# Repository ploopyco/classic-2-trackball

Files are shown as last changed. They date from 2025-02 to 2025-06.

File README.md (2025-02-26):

# The Ploopy Classic 2 Trackball

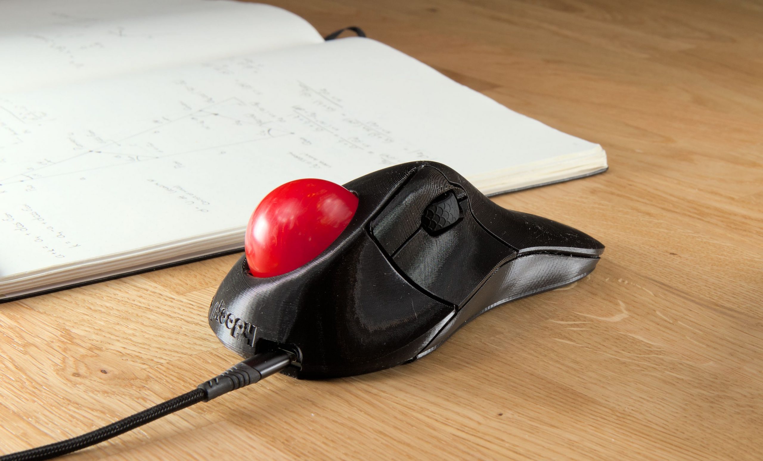
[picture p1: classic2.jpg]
The Ploopy Classic 2


By some stroke of luck, you've made your way here. The Ploopy Classic 2 Trackball. Your life will never be the same.

This repository contains all of the design and production files necessary to make a Ploopy Classic 2 Trackball. We've also included some kick-ass documentation on how to get it made, assemble it, and program it [which you can find here](https://ploopyco.github.io/classic-2-trackball/).

What are you waiting for? Your new life awaits.

## QMK?!

Kits bought from the [Ploopy store](https://ploopy.co/product-category/classic-2) come with QMK and VIA preloaded. [Check out the documentation](https://ploopyco.github.io/classic-2-trackball/) for instructions on how to load new firmware onto your device. (It's super easy!)

The firmware hex file that ships with all Classic 2 Trackballs is included in this repository as well, as `ploopyco_trackball_rev1_007_via.uf2`.

## Under what license is this released?

As per QMK's licensing requirements, the firmware for the Ploopy Classic 2 Trackball is released under GPLv3. Hardware design files, including electronics and mechanical files, are released under OHL CERN v2-S. Check the respective directories for full license text.

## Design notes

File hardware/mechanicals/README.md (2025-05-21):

## Revision J or K?

The *current* revision of the parts is Revision K. Revision J was shipped on Classic 2s prior to May of 2025.

If you're replacing parts from your current Classic 2, open it and check the Base. It should have a very prominent J or K written on it.

## Only one file? Where are the parts?

The STEP/STL files contain all of the plastic parts in one file. Doing it this way preserves the assembly information, showing how the parts are supposed to fit together, as well as the expected clearances between parts. It also bundles all of the parts for a given revision together, so there's no accidental mixing of parts from different revisions.

## How do I print this?

You'll need to split the parts in the file up before you can print them. Most slicers can do this; if you have a compatible printer we recommend PrusaSlic3r, since that's the one we use in-house and have checked.

Note that submitting this file to some 3rd party print services will cause confusion, as they are expecting one body instead of many. To do this, you can use PrusaSlic3r to split the parts and then export each separately as an STL.

## How can I use the included .3mf file?

The .3mf file was generated using PrusaSlicer v2.9. The job was generated for Prusa i3 MK2S/MK3S/MK3S+ printers. It assumes the use of PLA that is printable at 200-230C. If you have that PrusaSlicer version, such a printer, and such filament, then you're in a lot of luck! We use a .3mf job that is very similar to this one to print these parts on our printing farm.

If you do not, then using the included .3mf file is likely going to cause you a lot of headaches. If this is the case, the included .3mf file should be considered **as a reference only**. If you use it at all, it is recommended that you look at it to see what kinds of print settings we use (gyroid infill, 0.3mm layer height, part orientation, etc.). However, you should use your own slicing software to generate the .gcode files for your printer.

## Why don't you include a .gcode file?

For your safety. Uploading a .gcode file onto a printer can be extremely hazardous if that .gcode file wasn't specifically generated for that printer. We don't want to come anywhere near that sort of scenario, so we are not going to upload a .gcode file.

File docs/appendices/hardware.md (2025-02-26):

# Appendix C: Hardware

# Buying hardware from us

Getting all of the hardware on your own can be tricky because the parts you select may not fit perfectly. [That's why we sell kits with everything you need to build a Ploopy Classic 2 Trackball](https://ploopy.co/product-category/classic-2/). Here's why that's great for you:

- Everything is guaranteed to fit together perfectly
- Everything is guaranteed to work as intended
- You'll end up saving money - probably quite a bit of money - by not spending on extra parts

Your call. You'll sort it out.

# Getting your own hardware

This guide was a bit light on detail in the other sections, and that's because the hardware has to conform to many specifications. They'll all be listed here.

First, a complete list of all the hardware you'll need:

- 6x screws
- 3x MR63ZZ roller bearings
- 2x 3mm x 18mm metal dowels
- 1x silicone ring
- 4x friction pads
- 1x snooker ball

We'll be going over all of them in detail. There will be mentions of *critical specifications*; if you're going to be sourcing your own parts, **you must get parts that conform to the critical specifications**. If you go off-menu, the parts will not fit the way that we intended when we designed the Classic 2. That might mean that your Classic 2 **doesn't work**.

Let's get cracking.

## Screws

Here are the critical specifications:

- \#2
- 3/8" length

## MR63ZZ Roller Bearings

Here are the critical specifications:

- MR63ZZ bearing
- 3mm inner diameter
- 6mm outer diameter
- 2.5mm thickness

## 3mm x 18mm metal dowels

Here are the critical specifications:

- 3mm diameter
- 18mm length

## Silicone ring

We use decorative rings for this. Here are the critical specifications:

- Size 10 (19.8mm diameter)
- Width between 8.0mm and 8.7mm

## Friction pads

Here are the critical specifications:

- Circular shape
- Up to 3/4" diameter
- Up to 1/8" thickness
- Non-slip

## Snooker ball

We use 1.75-inch diameter (44.45mm) miniature snooker balls. Any ball between 44.5mm and 45.5mm should work.

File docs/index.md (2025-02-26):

# Home

So, you want to build a Ploopy Classic 2 Trackball, eh? Or, maybe you want to replace some broken parts. Maybe you want to reprogram it. Or maybe you just want to know how it all works. No matter the motivation, this is the place to learn.

**Bought a kit and itching to get it built?** --> Get started by going to the [assembly instructions](assembly-instructions.md).

**Looking to purchase a kit with everything you need to build your own Ploopy Classic 2 Trackball?** --> [Check out the Ploopy store](https://ploopy.co/product-category/classic-2).

**Building a Ploopy Classic 2 Trackball from scratch?** --> Get started by going to [Appendix A: Printed circuit boards](appendices/pcbs.md).

---

*Copyright (C) 2025 Ploopy Corporation. Permission is granted to copy, distribute and/or modify this document under the terms of the GNU Free Documentation License, Version 1.3 or any later version published by the Free Software Foundation; with no Invariant Sections, no Front-Cover Texts, and no Back-Cover Texts. A copy of the license is included in the section entitled "GNU Free Documentation License".*

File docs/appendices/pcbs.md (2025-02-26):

# Appendix A: Printed circuit boards

## Buying boards from us
Getting the Ploopy boards made can be complex, and expensive, especially if you only need one set. [That's why we sell kits with everything you need to build a Ploopy Classic 2 Trackball](https://ploopy.co/product-category/classic-2/). Here's why that's great for you:

- You get a PCB with all components soldered
- The firmware is already programmed on the microcontroller, so you won't have to program it
- It'll cost a hell of a lot less than if you do a production run of PCBs just for yourself
- You won't have to order components and wait while they come in
- We guarantee that it works

Just something to consider. You're smart. You'll figure it out.

## Making your own boards

Want to make your own Ploopy Classic 2 boards? Great! Less work for us. Seriously, though, only choose this option if you know what you're doing. You don't want to embarrass yourself, do you?

### Step 1: Order the PCBs from a PCB production company

Here are the most important configurations you'll need to communicate to the company:

- 4 layers
- FR-4, TG 150-160 (basically, whatever the cheapest option is)
- 1.6mm thickness
- 6/6mil track/spacing distance
- 0.3mm minimum hole size
- ENIG surface finish, but you can go with HASL if you don't care about lead poisoning
- 1oz copper thickness for both outer and inner layers
- Choose whatever colours you want for solder mask and silkscreen; we like white solder mask and black silkscreen

If something is missing from here, it's not really important.

At some point, you'll have to upload design files to the production company. Use the [electronics source files](https://github.com/ploopyco/classic-2-trackball/tree/master/hardware/electronics) to generate manufacturing files (you'll have to convert them from their native Altium format if you're using some other platform). That should contain everything you need to get the boards made. If the production company rejects this package, however, you'll need to address the issue yourself.

### Step 2: Order the electronics components

All of the components are described in the schematics of the PCBs. Ordering the components is left as an exercise for the reader.

A complete list of all of the components can be found in the electrical design files.

### Step 3: Get the necessary tools

- PCB
- All of the electronics components
- A hot air rework tool
- Solder paste
- A printout of the schematics

### Step 4: Solder the components to the boards

Once you've got the PCBs and all of the components, print out the schematics. Use the schematics to match the reference designators on the PCBs to the reference designators on the schematics, and then get to soldering.

If you've never soldered surface mount components before, or want a refresher on how to solder, we recommend [this video on using an iron to solder surface mount components](https://www.youtube.com/watch?v=3NN7UGWYmBY), and [this video on using a hot-air soldering station](https://www.youtube.com/watch?v=c_Qt5CtUlqY).

### Step 5: All done!

Congrats, you finished assembling the electronics! Pat yourself on the back.

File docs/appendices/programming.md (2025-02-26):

# Appendix D: QMK Firmware Programming

## Working with QMK

Ploopy devices are fairly easy to program and reprogram, thanks to the excellent work by all of the developers and maintainers of the [QMK firmware suite](https://github.com/qmk/qmk_firmware).

## Before you begin

If you have never used QMK before, go through [all of the steps in the QMK guide to set up your environment](https://docs.qmk.fm/#/newbs_getting_started).

QMK was built for keyboards, so you'll see lots of references to code that looks like the following:

`-kb <keyboard>`

Whenever you see that, use the following syntax:

`-kb ploopyco/trackball`

and you'll be fine.

## Building the Ploopy device firmware

Using QMK MSYS or your compilation toolchain of choice, compile the firmware with the following command:

`qmk compile -kb ploopyco/trackball/rev1_007 -km default`

Note: in the QMK namespace, the Classic (both the original and the Classic 2) is simply called "trackball". `rev1_007` is the firmware that ships on the Classic 2.

For more details on building QMK firmware in general, see the [QMK firmware guide](https://docs.qmk.fm/#/newbs_building_firmware).

## Putting the Ploopy device into bootloader mode

Putting the Ploopy device into bootloader mode is very simple and straightforward.

1. Unplug the device from your computer.
2. Hold the "back" button. This is the button just to the right of the ball; it normally sits under your ring (fourth) finger.
6. While holding the button, plug the Ploopy device into your computer..
7. The computer should recognise that a mass storage device was just plugged in. Once this is done, you should be able to drag and drop files onto the Ploopy device, as if the board was a USB drive. Feel free to remove the tweezers or paperclip at this point.

And that's it. While plugged in this way, the Ploopy device will accept new firmware.

If you want to upload a new firmware file (a ".uf2" file, like "ploopy_classic_2_v42069" or something), just drag it into the folder, and it'll automatically install on the Ploopy device and restart itself.

Whenever you want to put new firmware onto the Ploopy device, go through these steps again.

**TIP**: If your firmware is in some kind of strange state and uploading new firmware isn't fixing it, try uploading [a flash nuke](https://learn.adafruit.com/getting-started-with-raspberry-pi-pico-circuitpython/circuitpython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) to the Classic 2 before flashing the new firmware. It wipes the memory of the Trackpad completely clean, which can help clear a few types of errors.

## Putting the Ploopy device into bootloader mode if it's bricked

Putting the Ploopy device into bootloader mode if it's bricked is a bit more involved, but still doable.

1. Unplug it from your computer.
2. Open it by removing the screws in the Base and removing the Top.
3. Look for a pair of vias (gold-plated holes) on the board, with the text `BOOT LOADER` close by.
4. Get a paper clip (non-insulated, i.e. no plastic shit covering it) or a pair of tweezers, or some wire. Whatever you've got on hand that's metal.
5. Stick the paper clip or tweezers into the holes. You're trying to form an electrical connection between the two holes.
6. While you've got the two vias connected with your metal bridge, plug the Ploopy device into your computer.
7. The computer should recognise that a mass storage device was just plugged in. Once this is done, you should be able to drag and drop files onto the Ploopy device, as if the board was a USB drive. Feel free to remove the tweezers or paperclip at this point.

And that's it. While plugged in this way, the Ploopy device will accept new firmware.

## And that's it!

Happy customizing!

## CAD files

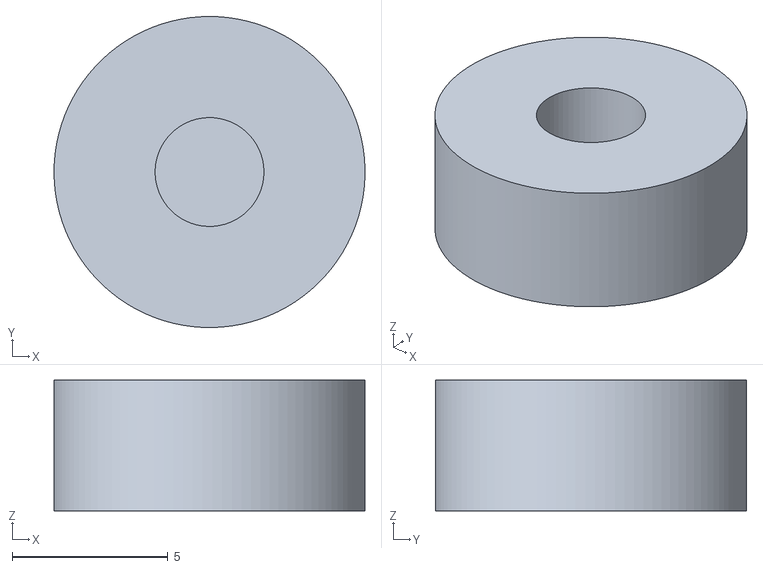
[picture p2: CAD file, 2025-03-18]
hardware/mechanicals/Bearing Press Jig Bottom.stl
10.00 x 10.00 x 4.20

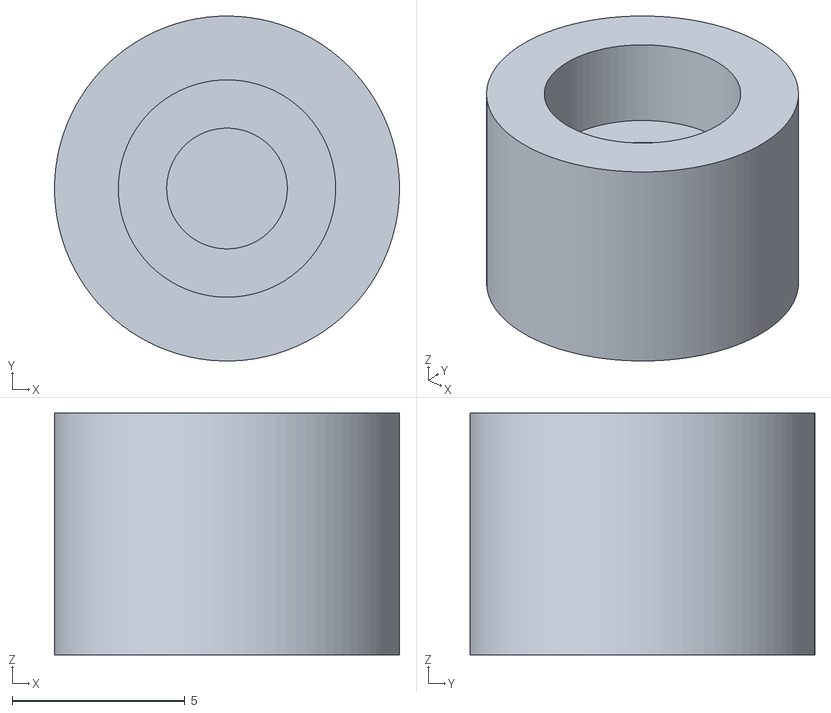
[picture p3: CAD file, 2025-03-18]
hardware/mechanicals/Bearing Press Jig Top.stl
10.00 x 10.00 x 7.00

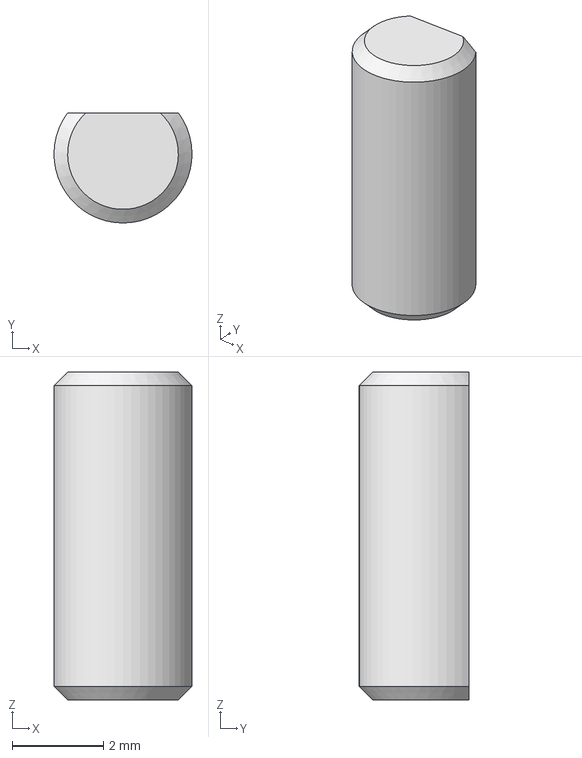
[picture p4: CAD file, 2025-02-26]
hardware/mechanicals/RollerBearingDowel.stp
3.03 x 2.42 x 7.20 mm

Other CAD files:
hardware/mechanicals/RollerBearingDowel.stl

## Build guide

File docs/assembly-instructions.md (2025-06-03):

# Ploopy Kit Assembly Instructions

## BEFORE YOU DO ANYTHING, READ THIS FIRST.

**Do not flash new firmware until you've verified that the electronics are all working.**

That means, finish building the Classic 2, plug it in, use the stock firmware for about five minutes. Verify that the cursor is moving, and all the buttons are working.

Once you've verified that it all works, you're good to go flashing new firmware.

## Do I have the right version of the Classic Trackball?

This guide is for building the Classic 2 Trackball. If your Classic kit has a large, bulky USB-B port on it, [you're looking for the original Classic assembly instructions, here](https://github.com/ploopyco/classic-trackball).

If your Classic has a **USB-C** connector on it, read onwards!

## Main Instructions


In this section, you'll go over how to build a Classic 2 from the official Ploopy Classic 2 kit.

Here's how these instructions are structured*:

- 💡 Comments with a lightbulb are good information to know.
- ➡️ Comments with an arrow are commands. Execute them when you encounter them.
- ✅ Comments with a checkmark are verification steps. Check what they tell you to check, and if it's all good, move on.
- 📷 Comments with a camera are references to photos. Check the corresponding image for guidance.

Most steps have photos, so if you need some additional visual help, consult the images.

Note that some of these pictures were taken at different times, so they may show a bit of inconsistency in between steps.

*\* Thanks to [schneems](https://github.com/schneems) for his [great suggestions on how to write documentation](https://github.com/ploopyco/headphones/issues/37).*

### Step 1

- ➡️ Get a soldering iron and solder.
- ➡️ Get a #1 Phillips head screwdriver (or similar; you're looking for a small-ish screwdriver here).
- 💡 A pair of needle-nose pliers and a pair of tweezers are optional, but they'll make future steps easier.

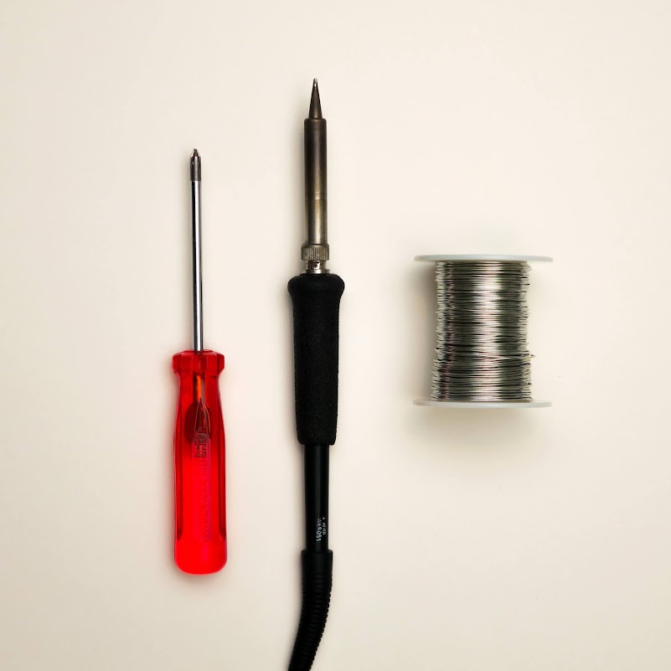
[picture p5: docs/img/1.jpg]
|  |
|:--:|
| *Figure 1: Necessary tools* |

### Step 2

- 💡 In the photo, a "tab" is being pulled by a pair of pliers.
- 💡 There may be up to two small tabs on the outside of the PCB.
- 💡 A pair of pliers will help to gently break the tabs off.
- ➡️ Break any leftover tabs off the PCB.

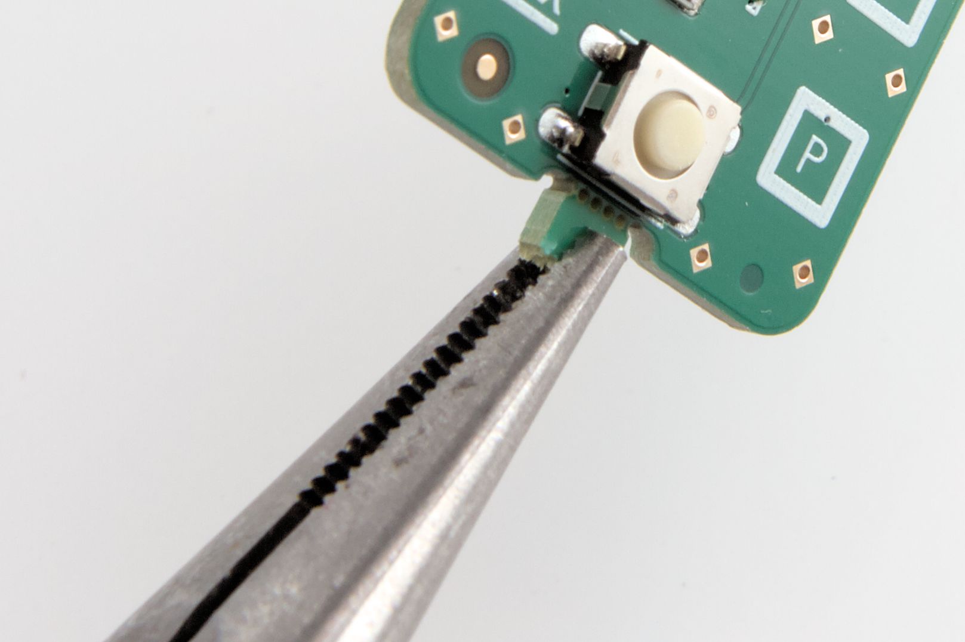
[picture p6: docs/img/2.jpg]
|  |
|:--:|
| *Figure 2: Breaking off tabs* |

### Step 3

- ➡️ Get the Base PCB and the PMW-3360.
- 💡 The PMW-3360 comes on a pink foam. This is a special anti-static foam that protects the PMW-3360 when it's being transported.
- ➡️ Remove the PMW-3360 from its foam.
- 💡 It is very, very easy to solder the PMW-3360 incorrectly. This mistake is almost impossible to fix and will permanently ruin the Classic 2. Follow the next steps very carefully.
- ✅ Make sure that you see the "Pin 1" dot on the PMW-3360. It's a small, white dot on the back of the chip. 📷 *See Figure 3.1 for details.*
- ✅ Make sure that you see the "1" designator on the Base PCB. 📷 *See Figure 3.2 for details.*
- 💡 The "Pin 1" dot on the PMW-3360 must be lined up correctly with the "1" designator on the Base PCB. 📷 *See Figure 3.3 for a photo showing the correct orientation of the sensor.*
- ➡️ Insert, but **do not solder**, the PMW-3360 into the Base PCB.

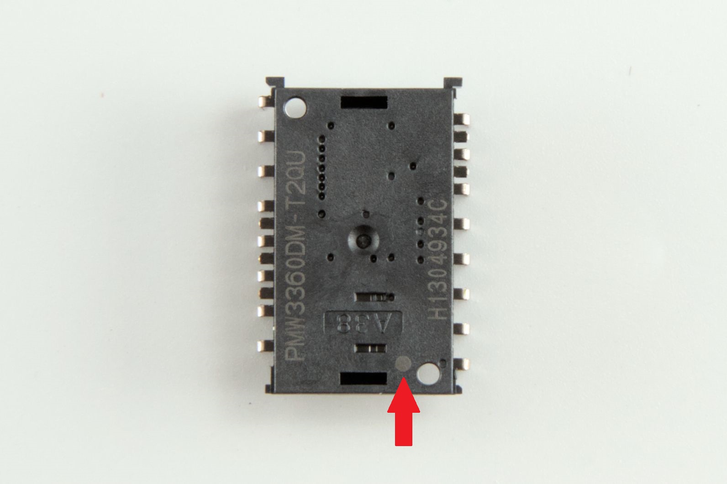
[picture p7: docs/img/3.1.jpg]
|  |
|:--:|
| *Figure 3.1: Pin 1 dot on the PMW-3360* |

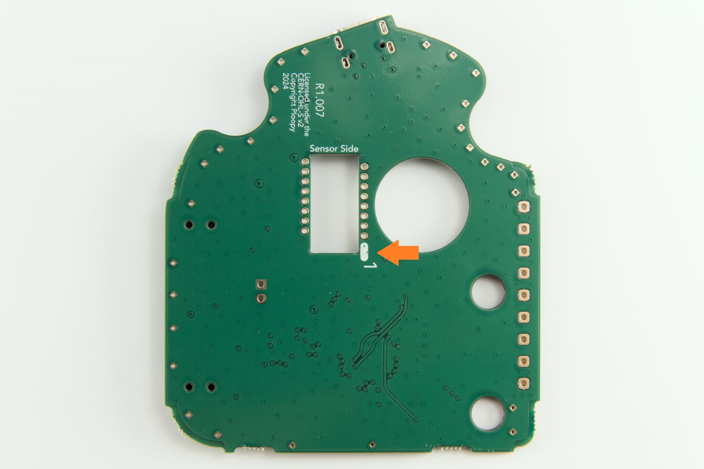
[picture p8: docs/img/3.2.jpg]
|  |
|:--:|
| *Figure 3.2: Pin 1 dot on the Base PCB* |

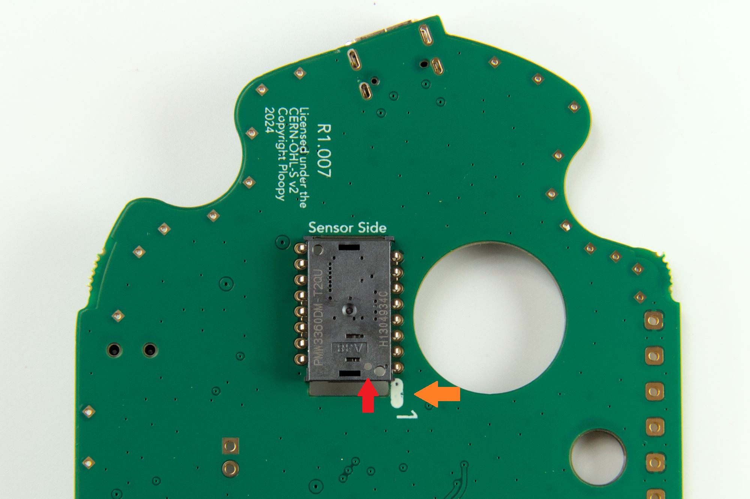
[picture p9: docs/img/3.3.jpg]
|  |
|:--:|
| *Figure 3.3: PMW-3360 correctly inserted into Base PCB* |

### Step 4

- 💡 In order to ensure that you have correctly lined up the PMW-3360 to the Base PCB, we're going to check this here.
- ✅ Find the white "Pin 1" dot on the PMW-3360, and the "1" designator on the PCB. Compare them again to what you see in 📷 Figure 3.3. Make sure that it lines up exactly the same way.
- ➡️ Orient the Base PCB so that it's lined up exactly the same as in 📷 Figure 3.3.
- ✅ Look at the text on the PMW-3360. Make sure that it's oriented the same way as it is in 📷 Figure 3.3.
- 💡 Quite a few people get through these instructions and still solder the sensor in backwards. Being diligent here will ensure that you're not one of them.
- ✅ **If you are sure that you oriented the PMW-3360 correctly, then proceed.**

### Step 5

- 💡 You're going to solder the sensor to the PCB in this step. Consider soldering a single pin while the Base PCB is upside down, specifically the pin *directly opposite* of the "1" designator (*see 📷 Figure 5.1*). After that, consider flipping the Base PCB so that it's right-side up and solder the rest of the pins. This ensures that the PMW-3360 is guaranteed to be in the right orientation.
- ➡️ Solder the PMW-3360 to the Base PCB.
- 💡 There are two small tabs of orange tape covering the sensors main holes. These protect the sensor from dust ingress during processing.
- ➡️ Remove the two small tabs of orange tape from the PMW-3360.
- 💡 Orient the optic correctly before insertion. It should not require a lot of force to insert fully; if it does, remove it and check the orientation before trying again.
- ➡️ Attach the optic to the PMW-3360. 📷 *See Figure 5.2 for details.*

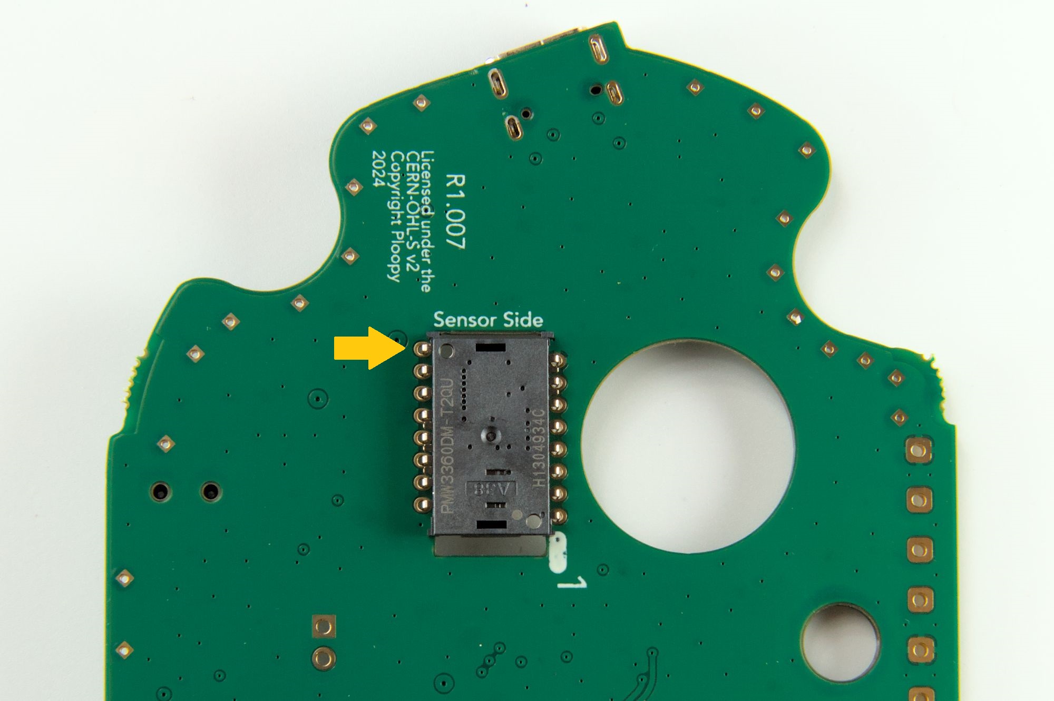
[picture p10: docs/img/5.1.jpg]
|  |
|:--:|
| *Figure 5.1: Recommended pin to start soldering* |

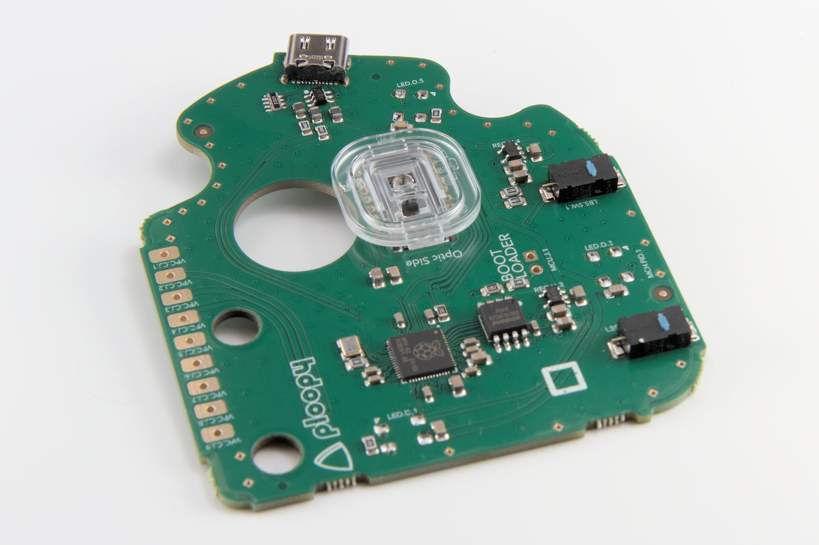
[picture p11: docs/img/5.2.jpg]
|  |
|:--:|
| *Figure 5.2: Optic attached to PMW-3360* |

### Step 6

- ➡️ Get the Base PCB, Vertical PCB, Electronics Assembly Jig, and PCB Anchor. 📷 *See Figure 6.1 for details.*
- 💡 The PCB Anchor should insert smoothly into both the Base PCB and Vertical PCB, but if you need to use a bit of force, go ahead.
- ➡️ Attach the PCB Anchor to the Base PCB. 📷 *See Figure 6.2 for details.*
- ➡️ Attach the Vertical PCB to the PCB Anchor. 📷 *See Figure 6.3 for details.*
- ➡️ Insert the PCBs into the Electronics Assembly Jig. 📷 *See Figure 6.4 for details.*
- ✅ Make sure that the PCBs are seated fully in the Electronics Assembly Jig.

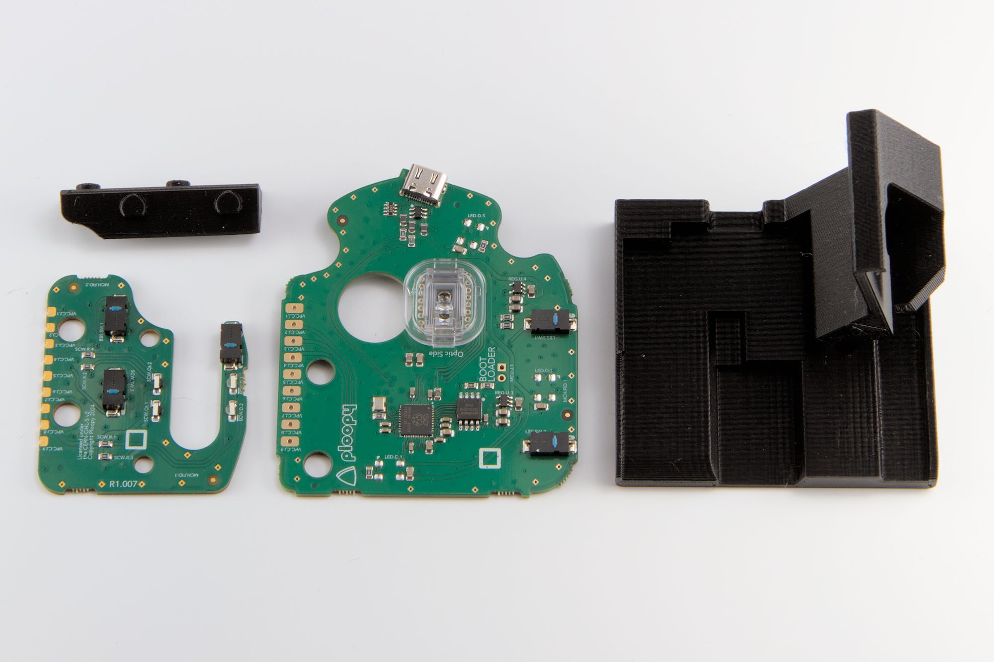
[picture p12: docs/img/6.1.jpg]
|  |
|:--:|
| *Figure 6.1: Base PCB, Vertical PCB, Electronics Assembly Jig, and PCB Anchor* |

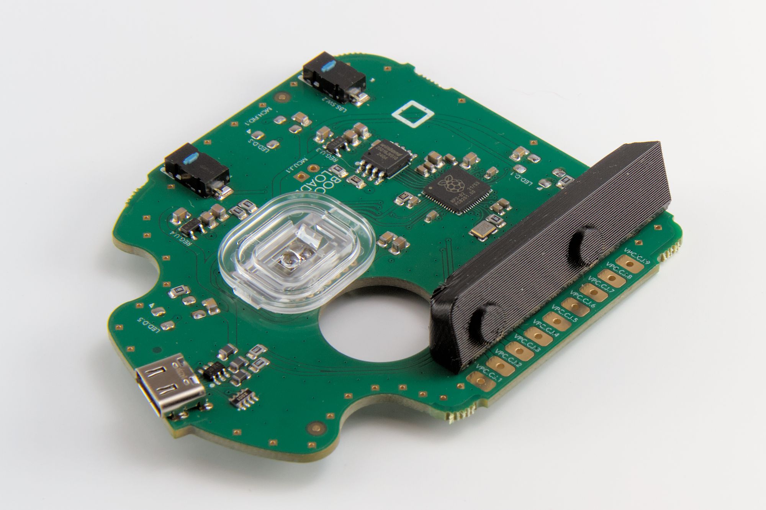
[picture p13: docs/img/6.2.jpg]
|  |
|:--:|
| *Figure 6.2: PCB Anchor in Base PCB* |

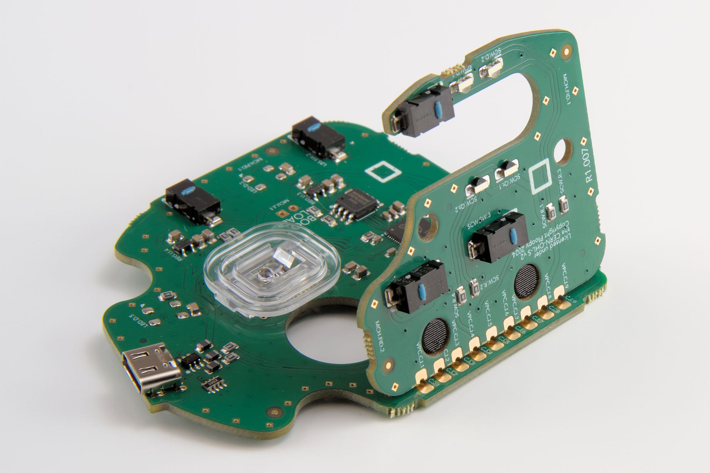
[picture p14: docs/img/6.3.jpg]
|  |
|:--:|
| *Figure 6.3: Vertical PCB in PCB Anchor* |

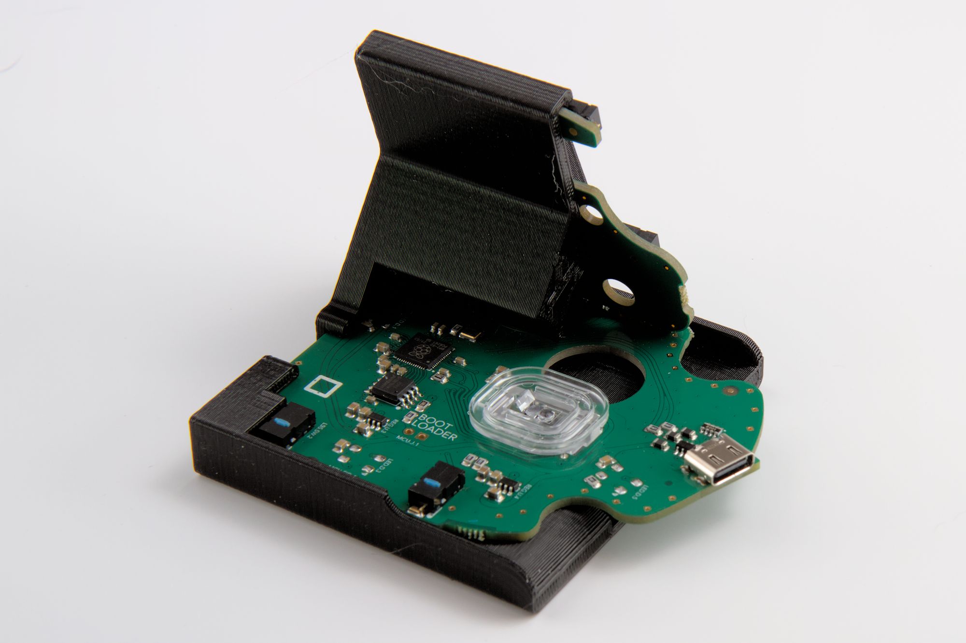
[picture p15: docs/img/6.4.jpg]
|  |
|:--:|
| *Figure 6.4: PCBs in Electronics Assembly Jig* |

### Step 7

- 💡 Soldering the pads of the Base PCB to the Vertical PCB provides a lot of mechanical strength to the entire assembly. You will probably use a lot more solder than you think.
- 💡 The PCB Anchor remains in place after the Base PCB is soldered to the Vertical PCB. Although some photos may show that it is not present after the boards have been soldered together, **do not remove it at any point**.
- 💡 You're looking for a smooth fillet between the pads of the PCBs, not a bulging joint.
- 💡 Consider setting the soldering iron's temperature to around 20C higher than normal, as the pads are large and shed heat quickly. This is especially true for Pads 1, 5 and 9 (a.k.a. the pads on either end of the row, and the middle pad). 📷 *See Figure 7.1 for details.*
- ➡️ Solder the Base PCB to the Vertical PCB. 📷 *See Figure 7.2 for details.*
- ➡️ Once soldered, remove the completed PCBs from the Electronics Assembly Jig.

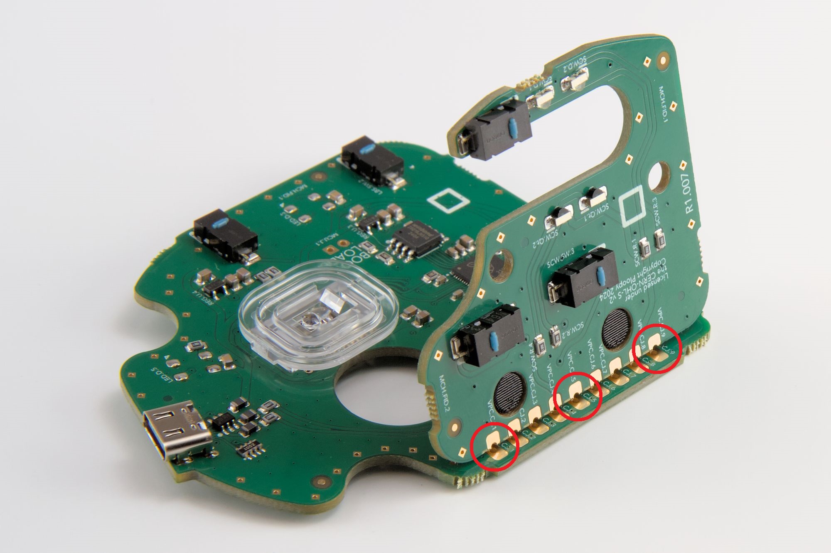
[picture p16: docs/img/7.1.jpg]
|  |
|:--:|
| *Figure 7.1: Pads that shed heat quickly* |

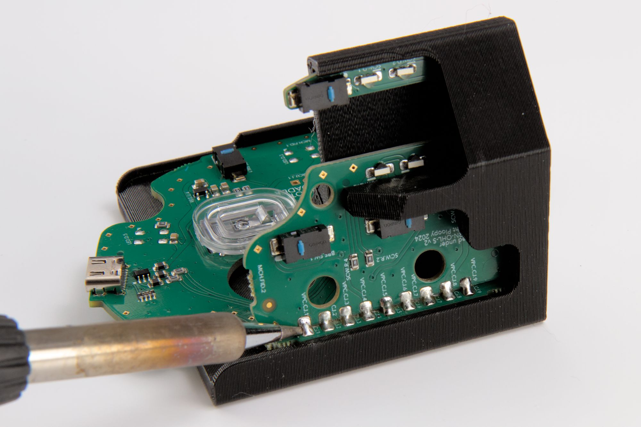
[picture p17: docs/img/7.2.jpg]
|  |
|:--:|
| *Figure 7.2: PCBs being soldered together* |

### Step 8

- 💡 The following 3D-printed parts have support material on them:
    - 💡 Top
    - 💡 Primary buttons
    - 💡 Secondary buttons
- 💡 "Support material" is more hollow than the structural plastic. You'll have to remove it before you continue with the assembly.
- 💡 You will probably have to use a pair of pliers or tweezers to scrape off support material, as it can stick rather vigourously. Be careful not to damage the parts as you remove the support material, **especially on the Scroll Wheel Holder Holder**.
- 💡 [Here's a video on removing support material](https://www.youtube.com/watch?v=qRsbkJuOWSM).
- ➡️ Remove all support material from 3D-printed parts.
- ✅ Insert of the Metal Dowels into the Top. If it fits snugly in the hole, continue. If it doesn't fit, use a pair of tweezers and scrape any loose support material out of the hole. 📷 *See Figure 8 for details.*

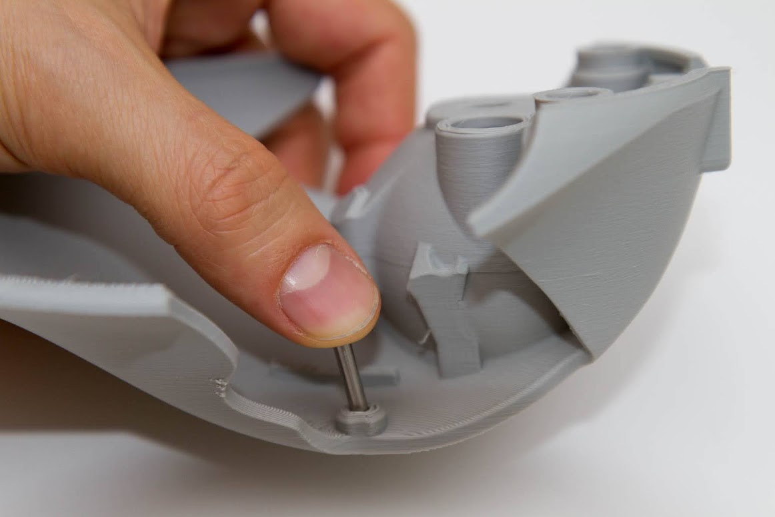
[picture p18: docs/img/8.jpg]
|  |
|:--:|
| *Figure 8: Checking hole in Top with a Metal Dowel* |

### Step 9

- 💡 Currently, the kits that we ship are **Revision K** (you can tell by looking at the Base, which has a "K" written on it).
- 💡 The *Scroll Wheel Holder Holder* design significantly changed between Revision J (which is shown in the following pictures) and the current Revision K.
- 📷 *See Video 9 for the current Scroll Wheel Holder Holder and how to insert it into the PCBs.*
- ➡️ Get the PCBs, Scroll Wheel Holder, and Scroll Wheel Holder Holder. 📷 *See Figure 9.1 for details.*
- 💡 There are **two** Scroll Wheel Holder Holders in your kit. The second is a spare; keep it somewhere safe.
- 💡 Inserting the Scroll Wheel Holder into the Scroll Wheel Holder Holder should be done very gently. These parts are quite delicate. Take your time and don't bend things unnecessarily.
- ➡️ Insert the Scroll Wheel Holder into the Scroll Wheel Holder Holder. 📷 *See Figure 9.2 for details.*
- 💡 During insertion of the Scroll Wheel Holder Holder into the PCB, press the Scroll Wheel Holder Holder on its edges, NOT the middle, as you may break the part if you depress the middle too hard.
- ➡️ Insert the Scroll Wheel Holder Holder into the PCBs. 📷 *See Figure 9.3 for details.*
- ✅ Check to see that the Scroll Wheel Holder Holder is flush against the PCB. If it isn't, try using the second Scroll Wheel Holder Holder in your kit to see if it fits better.
- 💡 Once you've finished building the Classic 2, if the scroll wheel button is very difficult to press, then it's probably because the Scroll Wheel Holder Holder isn't flush against the PCB.

| <video controls><source src="../img/9.mp4" type="video/mp4"></video> |
|:--:|
| *Video 9: Scroll Wheel Holder Holder, Revision K* |

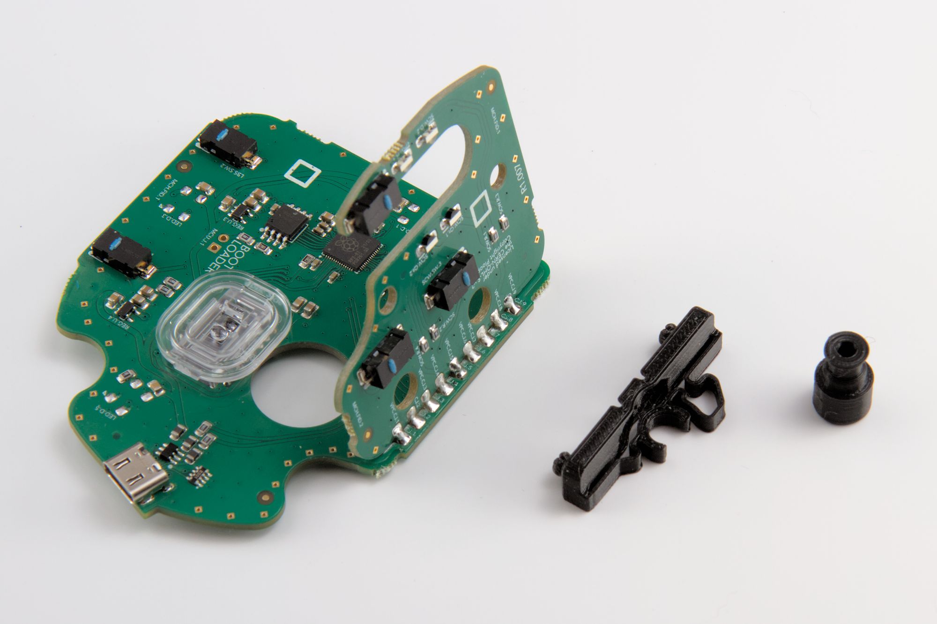
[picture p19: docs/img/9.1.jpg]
|  |
|:--:|
| *Figure 9.1: PCBs, Scroll Wheel Holder, and Scroll Wheel Holder Holder* |

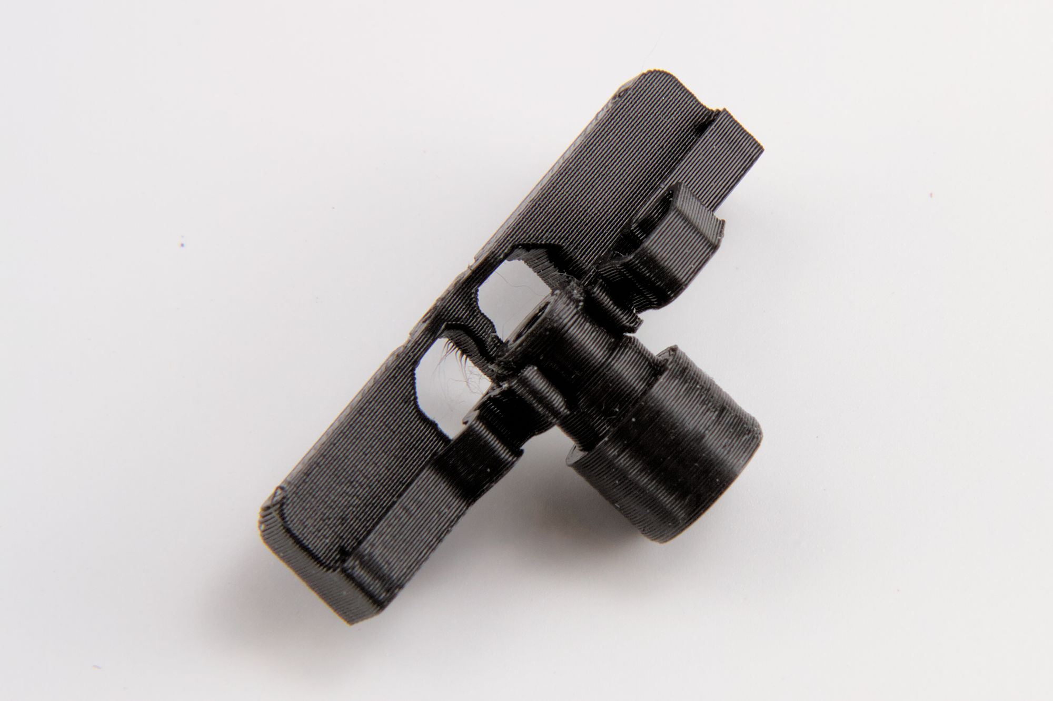
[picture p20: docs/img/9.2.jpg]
|  |
|:--:|
| *Figure 9.2: Scroll Wheel Holder inserted into the Scroll Wheel Holder Holder* |

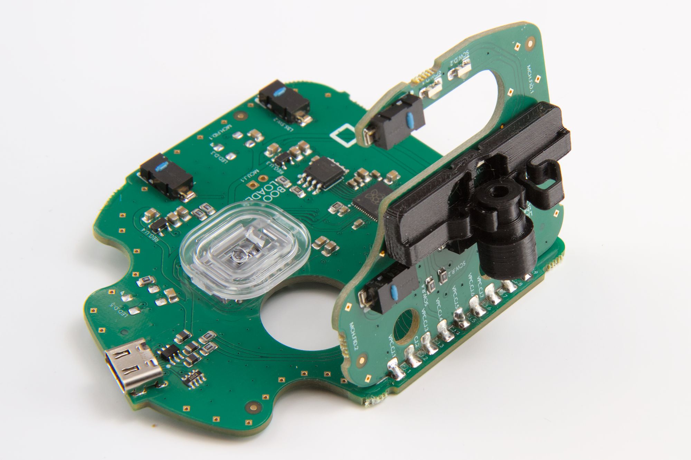
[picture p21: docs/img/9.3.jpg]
|  |
|:--:|
| *Figure 9.3: Scroll Wheel Holder Holder inserted into the PCBs* |

### Step 10

- ➡️ Get the Scroll Wheel, Silicone Ring, and 2x Metal Dowels. 📷 *See Figure 10.1 for details.*
- 💡 You will likely require a hammer to push the pin into the scroll wheel. If you don't need one, consider yourself lucky.
- 💡 The pin on the flat side of the scroll wheel will stick out 10.4mm when the pin is fully inserted. The pin on the other side of the scroll wheel will stuck out 13.6mm when the pin is fully inserted.
- ➡️ Insert the Metal Dowels into Scroll Wheel. 📷 *See Figure 10.2 for details.*
- ➡️ Thread the Silicone Ring onto the Scroll Wheel. 📷 *See Figure 10.3 for details.*
- 💡 When inserting the Scroll Wheel into the Scroll Wheel Holder, the parts can be bent slightly, but try hard to minimize the amount that they bend.
- ➡️ Insert the Scroll Wheel into the Scroll Wheel Holder. 📷 *See Figure 10.4 for details.*

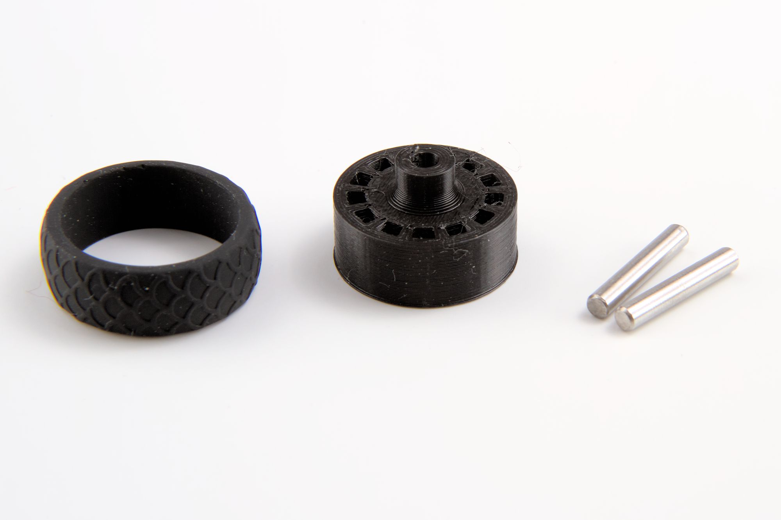
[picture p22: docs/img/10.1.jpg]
|  |
|:--:|
| *Figure 10.1: Scroll Wheel, Silicone Ring, and 2x Metal Dowels* |

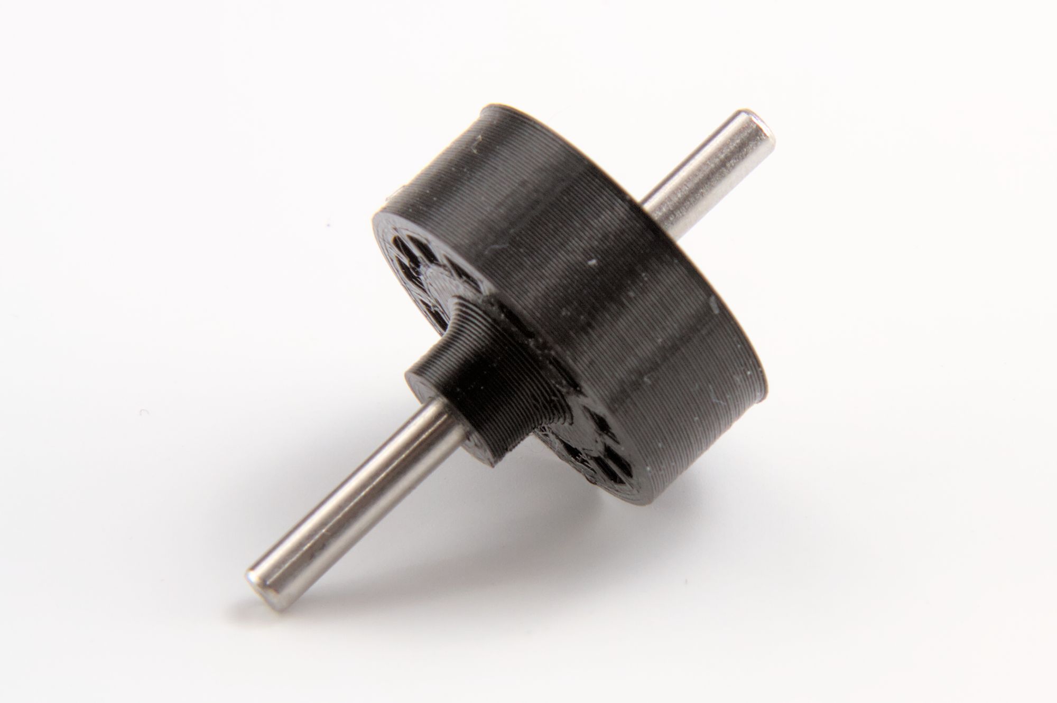
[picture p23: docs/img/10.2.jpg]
|  |
|:--:|
| *Figure 10.2: Metal Dowels in Scroll Wheel* |

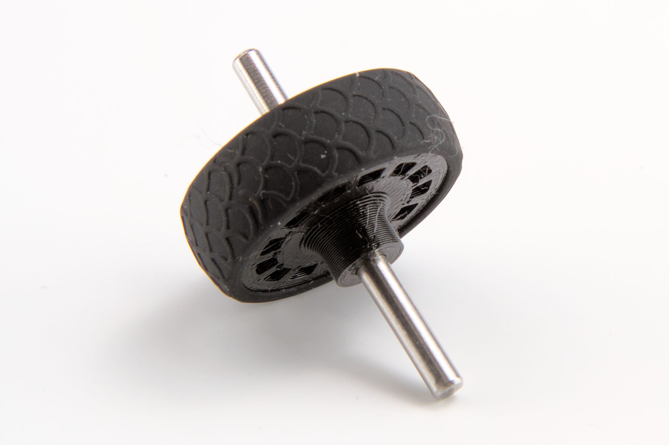
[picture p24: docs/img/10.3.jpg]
|  |
|:--:|
| *Figure 10.3: Silicone Ring on Scroll Wheel* |

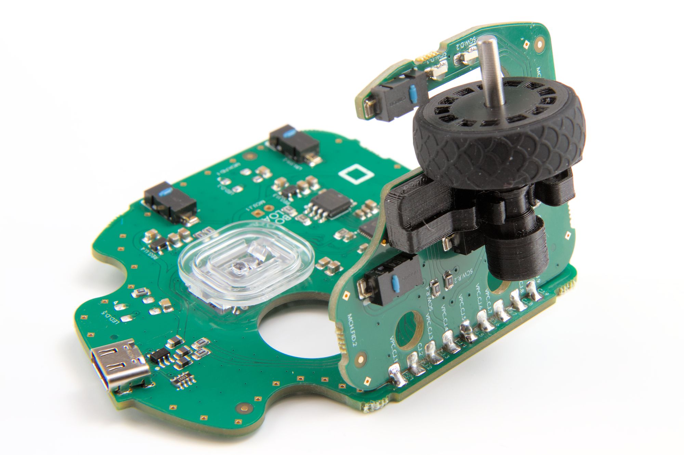
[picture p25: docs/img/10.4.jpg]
|  |
|:--:|
| *Figure 10.4: Scroll Wheel in Scroll Wheel Holder Holder* |

### Step 11

- ➡️ Get the PCBs, Base, Primary Buttons, Secondary Buttons, and 2x Screws. 📷 *See Figure 11.1 for details.*
- ➡️ Place the PCBS onto the Base. 📷 *See Figure 11.2 for details.*
- ➡️ Screw the Secondary Buttons into the Base. 📷 *See Figure 11.3 for details.*
- ➡️ Screw the Primary Buttons into the Base. 📷 *See Figure 11.4 for details.*

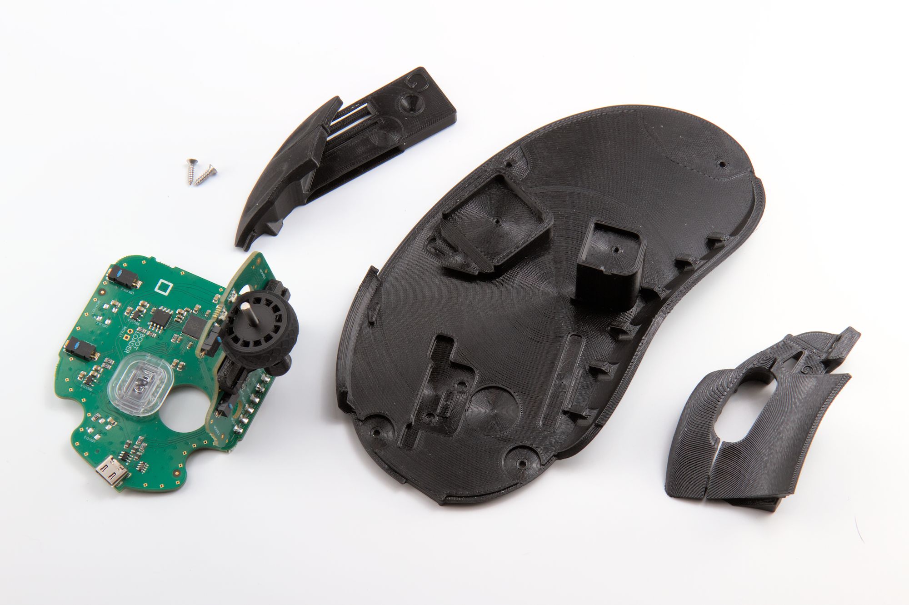
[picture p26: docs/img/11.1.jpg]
|  |
|:--:|
| *Figure 11.1: PCBs, Base, Primary Buttons, Secondary Buttons, and 2x Screws* |

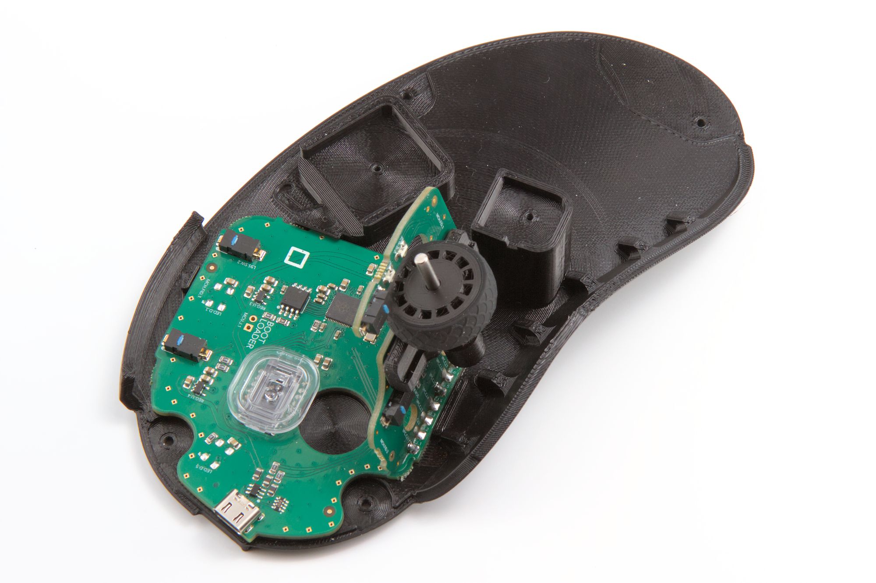
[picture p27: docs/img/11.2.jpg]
|  |
|:--:|
| *Figure 11.2: PCBs in Base* |

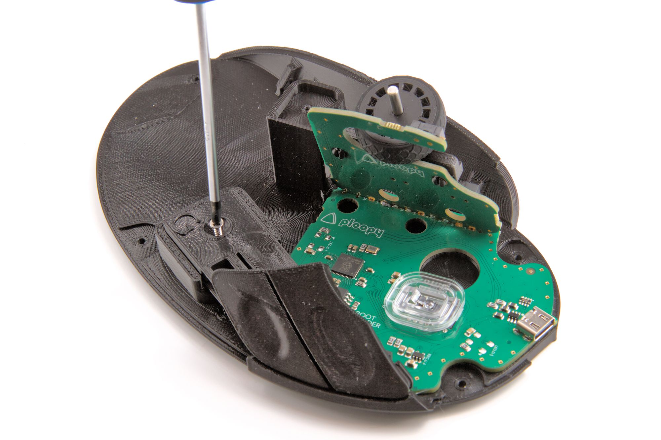
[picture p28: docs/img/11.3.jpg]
|  |
|:--:|
| *Figure 11.3: Secondary Buttons in Base* |

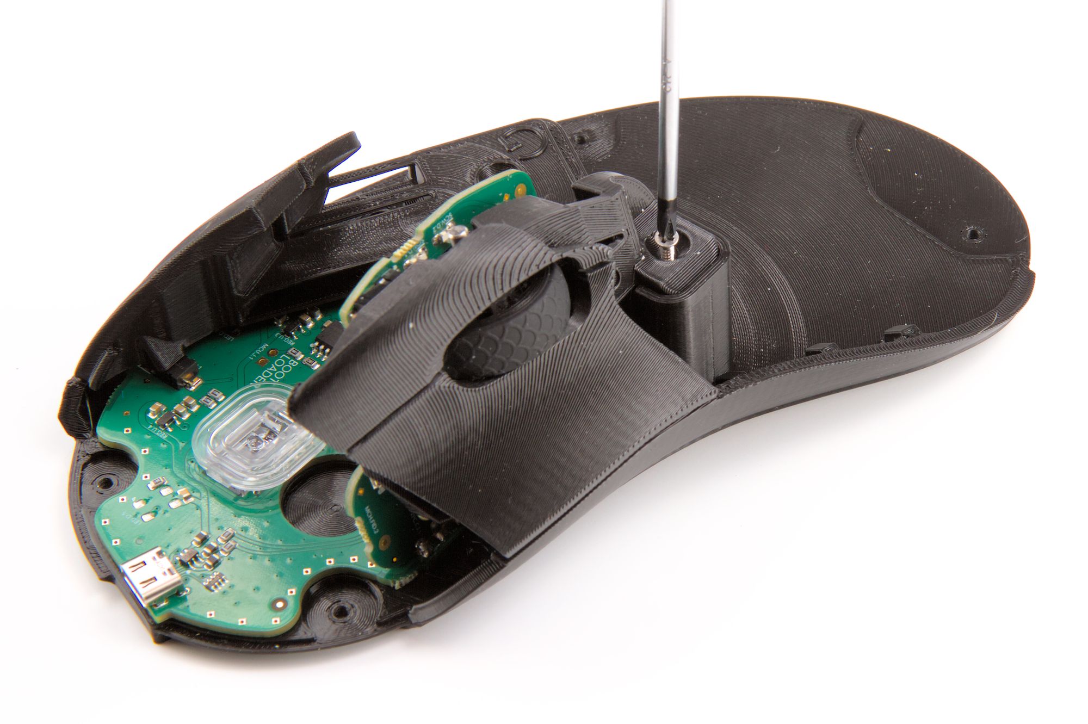
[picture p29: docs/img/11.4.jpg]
|  |
|:--:|
| *Figure 11.4: Primary Buttons in Base* |

### Step 12

- ➡️ Get 3x Roller Bearings, 3x Roller Bearing Dowels, and the Bearing Press Jig. 📷 *See Figure 12.1 for details.*
- ➡️ Insert a Roller Bearing and a Roller Bearing Dowel into the halves of the Bearing Press Jig. 📷 *See Figure 12.2 for details.*
- 💡 Pressing the halves of the Bearing Press Jig together may require a surprising amount of force.
- ➡️ Press the halves of the Bearing Press Jig together. 📷 *See Figure 12.3 for details.*
- ➡️ Remove the bearing from the Bearing Press Jig and repeat two more times for the other Roller Bearings. 📷 *See Figure 12.4 for details.*

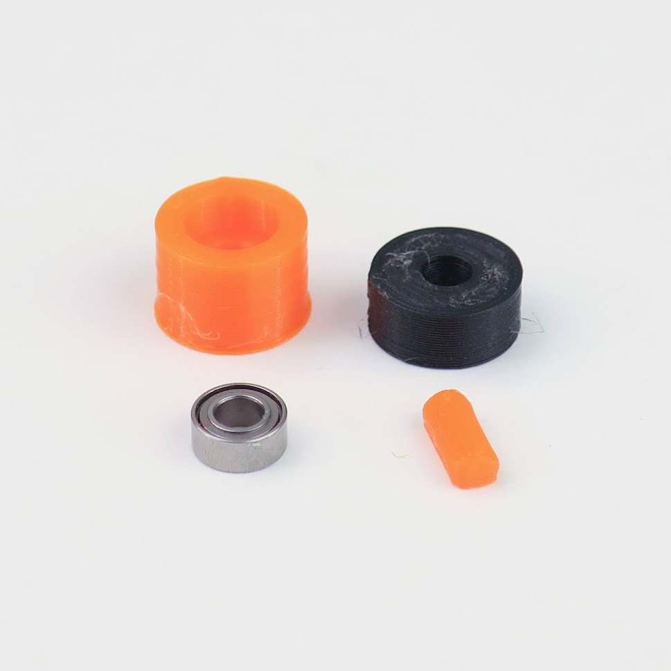
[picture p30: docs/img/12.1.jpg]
|  |
|:--:|
| *Figure 12.1: Roller Bearings, Roller Bearing Dowels, and the Bearing Press Jig* |

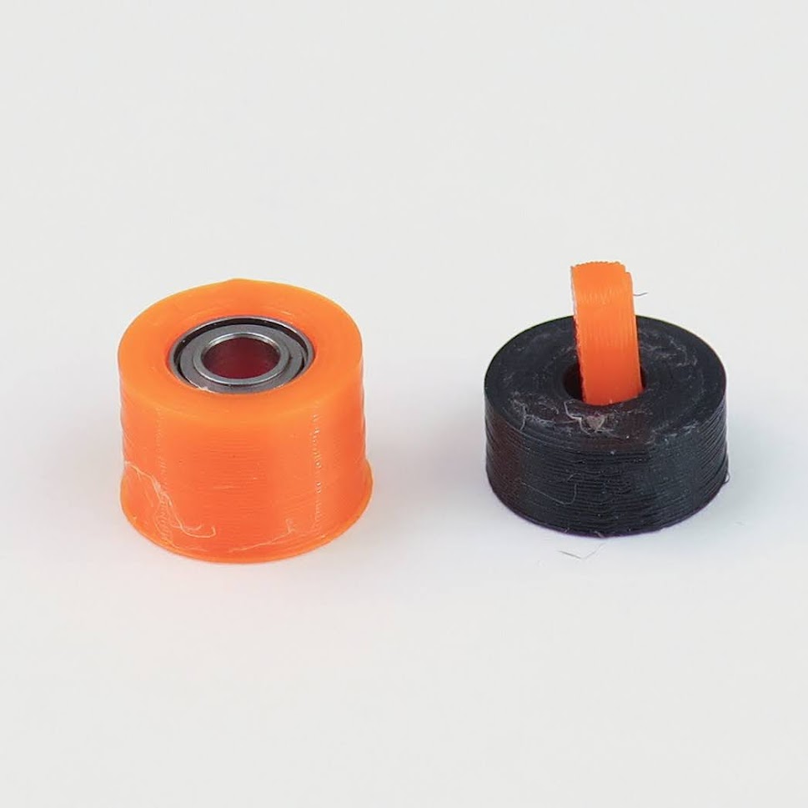
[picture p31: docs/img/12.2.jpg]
|  |
|:--:|
| *Figure 12.2: Roller Bearing and a Roller Bearing Dowel in the halves of the Bearing Press Jig* |

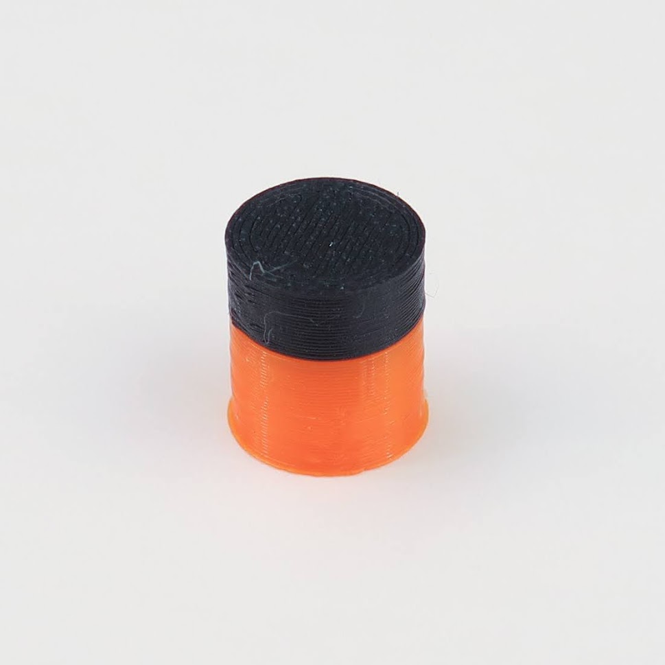
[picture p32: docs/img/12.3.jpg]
|  |
|:--:|
| *Figure 12.3: Halves of the Bearing Press Jig pressed together* |

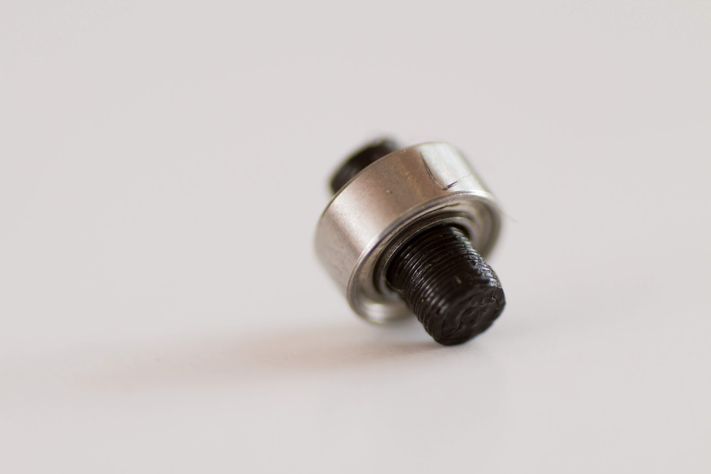
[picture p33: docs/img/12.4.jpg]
|  |
|:--:|
| *Figure 12.4: Completed Roller* |

### Step 13

- ➡️ Get the Top and 3x Rollers.
- 💡 Consider using needle nose pliers to press the Rollers into the Top as that will ensure that the Roller is fully seated.
- ➡️ Insert Rollers into the Top. 📷 *See Figure 13.2 for details.*
- 💡 If the Rollers aren't seated all the way, there's a good chance that tracking performance will be very bad.
- ✅ Ensure that the Rollers are pressed all the way into the Top, which may require quite a bit of force.

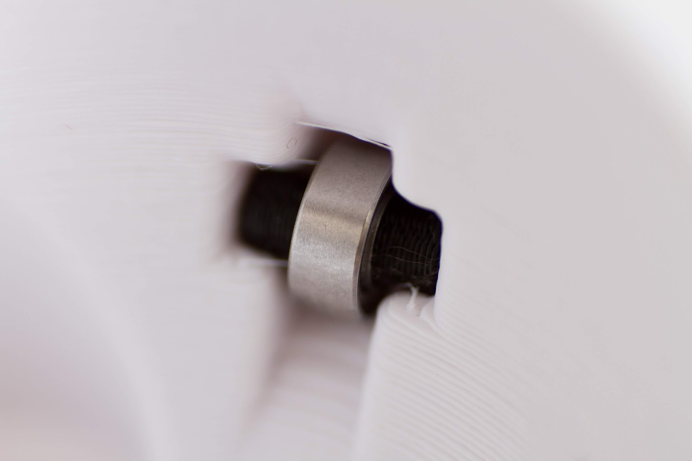
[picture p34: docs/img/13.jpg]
|  |
|:--:|
| *Figure 13: Roller inserted into Top* |

### Step 14

- 💡 To put the Top on:
    - 💡 Align the USB-C connector with the Top.
    - 💡 Put your thumb on the Primary Buttons and your index and middle finger on the Secondary Buttons, and depress the buttons gently. (They should click.)
    - 💡 Pull the Top (it will bend slightly) until the peg from the Scroll Wheel enters its sheath in the Top.
    - 💡 Press the Top into the Base with gentle but firm pressure until the two are seated together entirely.
    - 💡 [Here's a video showing the above steps](https://www.youtube.com/watch?v=o0BSe5tcxug).
- 💡 To remove the Top:
    - 💡 Put your thumb on the Primary Buttons and your index and middle finger on the secondary buttons, and depress the buttons gently. (They should click.)
    - 💡 Lift the rear end of the Top until the Scroll Wheel peg slips out of its sheath in the Top.
    - 💡 Pull the Top off.
    - 💡 [Here's a video showing the above steps](https://www.youtube.com/watch?v=IlaOSYDtQRs).
- ➡️ Put the Top onto the Base.

### Step 15

- ➡️ Insert the remaining 4x Screws into the Base to screw everything together.
- 💡 It doesn't really matter where the Friction Pads go, but we like to place them as they appear in 📷 Figure 15.
- ➡️ Apply the Friction Pads to the Base. 📷 *See Figure 15 for details.*
- ➡️ Insert the Ball.
- 💡 It's possible that the Secondary Buttons rotated "inwards" (towards the PMW sensor) while you were putting the Top on. If they rotate too far inwards, they can become stuck, and won't click. To fix this, use your finger or a pair of tweezers to gently rotate the Secondary Buttons "outwards" (away from the PMW sensor) until they begin to click again.

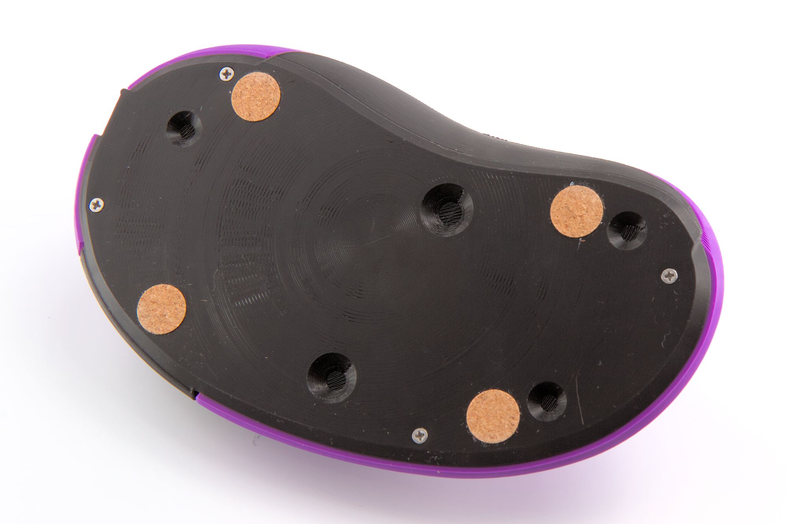
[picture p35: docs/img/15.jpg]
|  |
|:--:|
| *Figure 15: Screws and Friction Pads applied* |

### Step 16

- ➡️ Plug the Classic 2 into your computer.
- ✅ Check that moving the Ball moves the cursor.

### Step 17

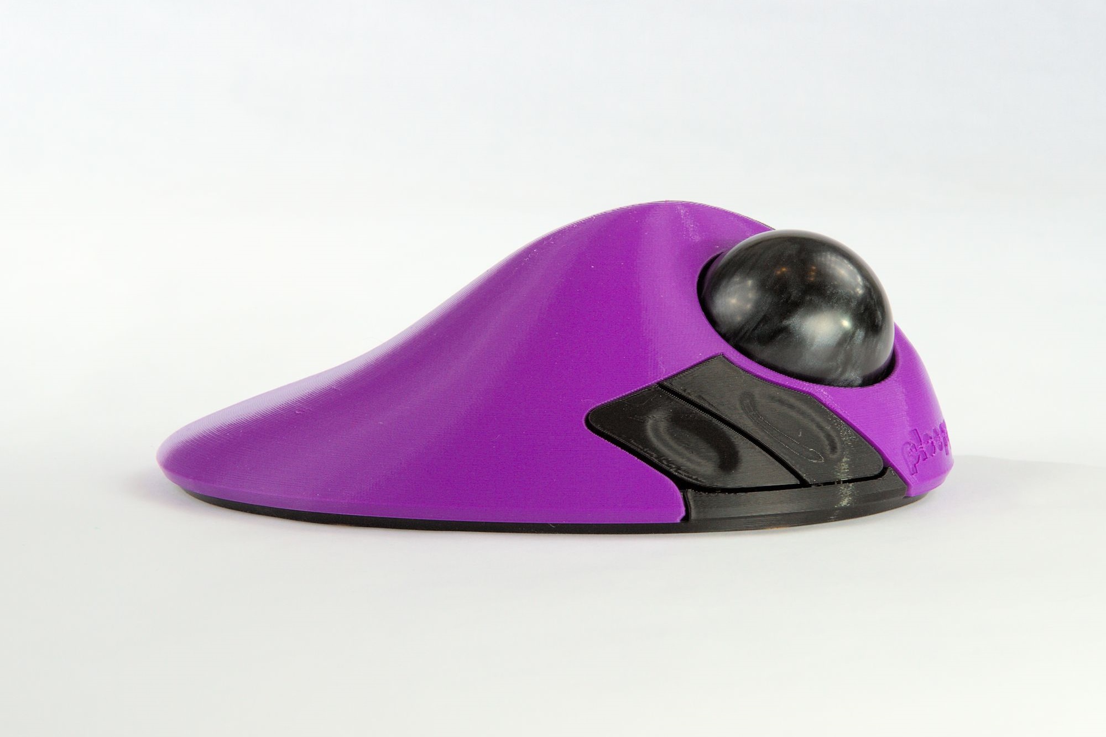
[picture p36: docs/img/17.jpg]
|  |
|:--:|
| *Figure 17: Completed Classic 2!* |

- 💡 Congrats, you finished building the Ploopy Classic 2!
- 💡 It's done! Love it, use it, but don't you dare abuse it!

## Troubleshooting

### My buttons "stick".

- 💡 If your buttons are stuck down and won't click, it's usually because the two front screws are too tight. 📷 *See Figure T1 for details.*
- ➡️ Loosen the two front screws. Turn each one by a quarter-turn (or 90 degrees).
- ✅ Check if the buttons click. If not, loosen the screws a bit more.

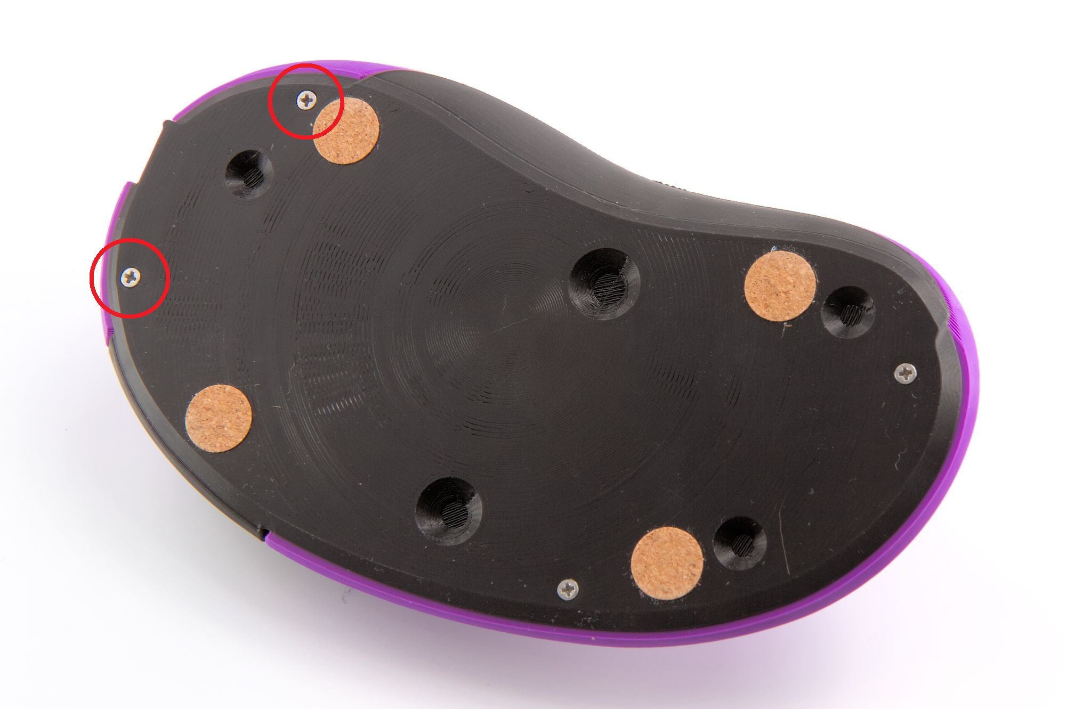
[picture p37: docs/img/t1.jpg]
|  |
|:--:|
| *Figure T1: Screws that cause button seizure* |

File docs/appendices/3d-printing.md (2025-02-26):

# Appendix B: 3D printed parts

# Buying 3D-printed parts from us
Not everyone has access to a 3D-printer. [That's why we sell kits with everything you need to build a Ploopy Classic 2 Trackball](https://ploopy.co/product-category/classic-2/). Here's why that's great for you:

- You get all of the 3D-printed parts, guaranteed free of manufacturing defects
- You won't waste time spending hours tweaking settings
- We guarantee it will fit together *perfectly*

Consider it. You're a smartie. You'll get there.

# Printing your own parts

So, you have a printer and want to print your own parts? Great! We don't have specific instructions, since every printer setup is different. All of the STLs are available, and if you need to make tweaks, you can alter the design files.

Here are the settings we use when we print parts. **Note that these settings have only been tested on the Prusa i3 MK2.5S and MK3S.** If you have another printer, you may need to tweak these settings.

- PLA. The geometry of many of the parts is quite complex; trying to use other materials may not result in success.
- 0.30mm layer height. You can go finer than this if you want, but we haven't tested that. Going coarser is not going to work; first, it's going to feel rough on your hand, and second, it won't accurately capture the necessary detail.
- Add supports to all of the pieces, but from the build plate only. They don't need to be everywhere.
- We changed the support material overhang threshold to 35 degrees (with the intention of reducing the amount of support material; some slicer programs have inverted settings, i.e. 55 degrees instead of 35, so do what's necessary). Any more support material is wasteful.
- Orient the pieces so that flat sides are on the build plate.
- We like gyroid for infill pattern, but anything is probably good. Cubic, rectilinear, whatever.
- We use 0.4mm nozzles. We haven't tested other nozzle sizes.

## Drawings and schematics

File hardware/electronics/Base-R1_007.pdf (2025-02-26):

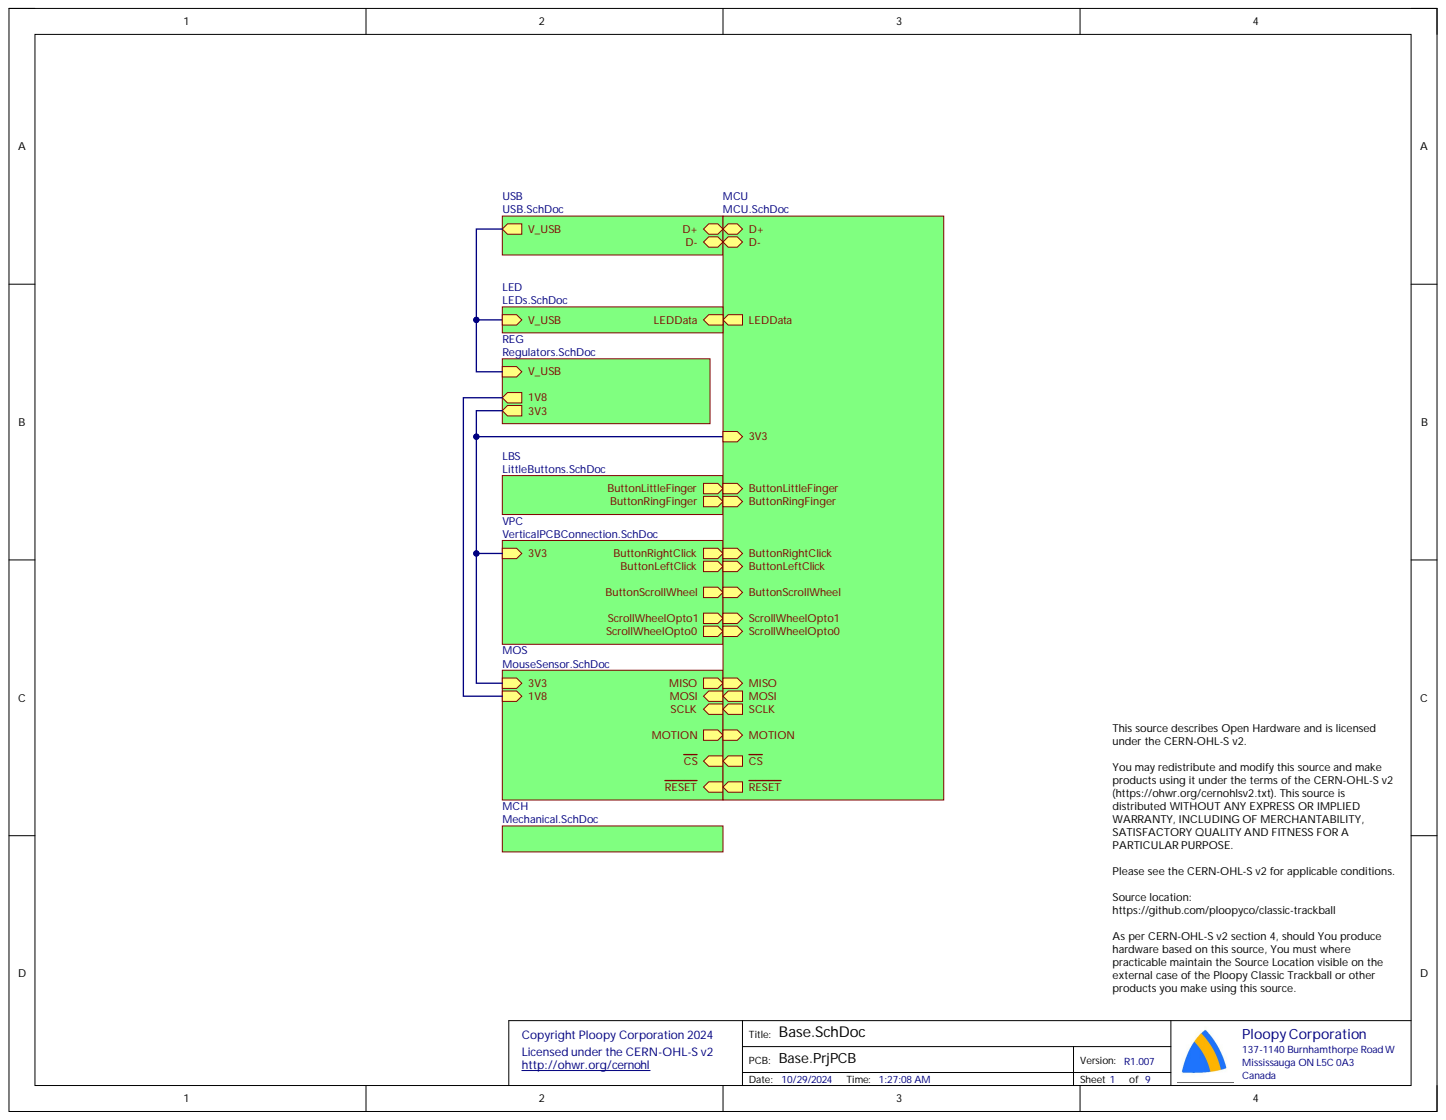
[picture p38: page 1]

This source describes Open Hardware and is licensed
under the CERN-OHL-S v2.

You may redistribute and modify this source and make
products using it under the terms of the CERN-OHL-S v2
(https://ohwr.org/cernohlsv2.txt). This source is
distributed WITHOUT ANY EXPRESS OR IMPLIED
WARRANTY, INCLUDING OF MERCHANTABILITY,
SATISFACTORY QUALITY AND FITNESS FOR A
PARTICULAR PURPOSE.

Please see the CERN-OHL-S v2 for applicable conditions.

Source location:
https://github.com/ploopyco/classic-trackball

As per CERN-OHL-S v2 section 4, should You produce
hardware based on this source, You must where
practicable maintain the Source Location visible on the
external case of the Ploopy Classic Trackball or other
products you make using this source.

Copyright Ploopy Corporation 2024
Licensed under the CERN-OHL-S v2
http://ohwr.org/cernohl

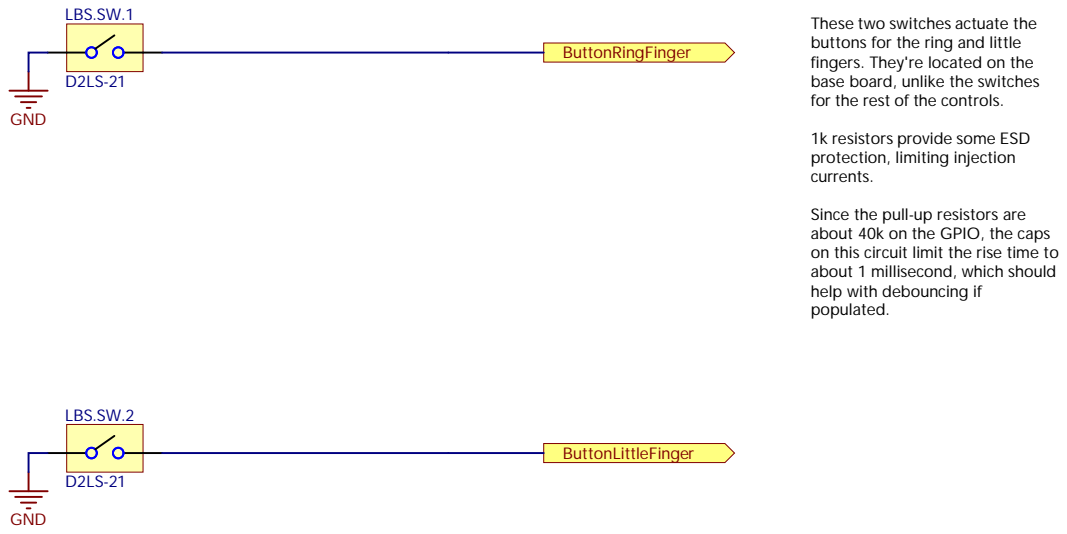
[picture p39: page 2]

These two switches actuate the
buttons for the ring and little
fingers. They're located on the
base board, unlike the switches
for the rest of the controls.

1k resistors provide some ESD
protection, limiting injection
currents.

Since the pull-up resistors are
about 40k on the GPIO, the caps
on this circuit limit the rise time to
about 1 millisecond, which should
help with debouncing if
populated.

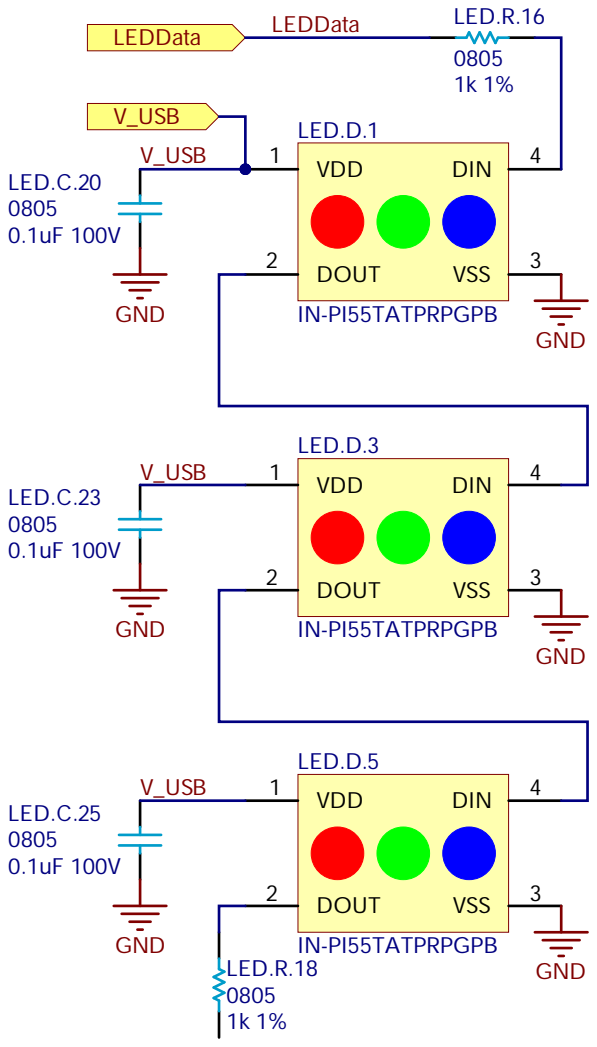
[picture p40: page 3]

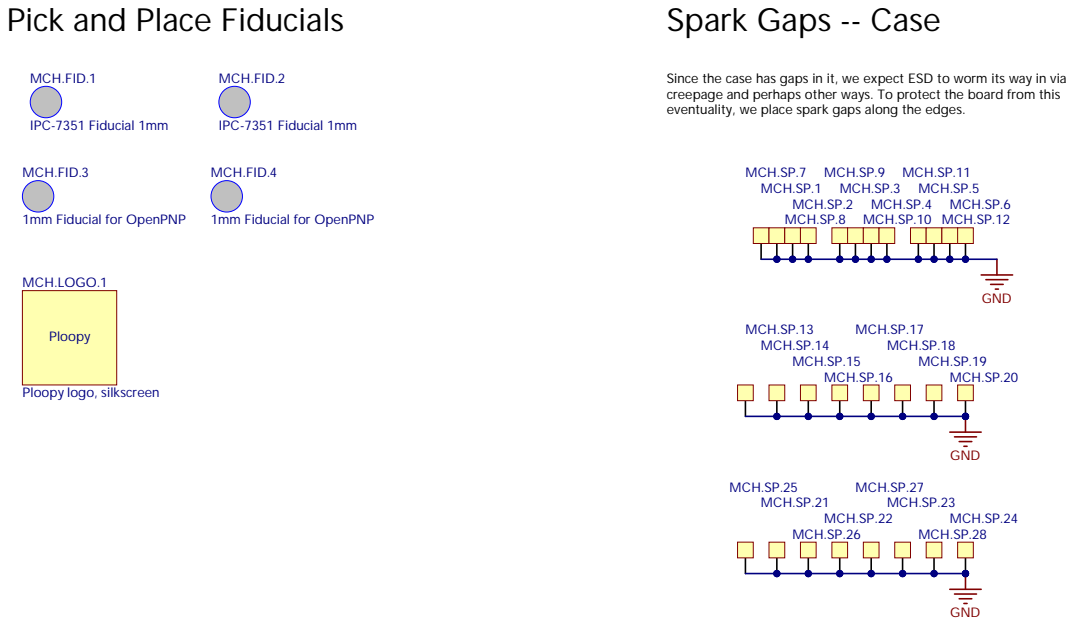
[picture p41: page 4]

Pick and Place Fiducials

Spark Gaps -- Case MCH.SP.7 MCH.SP.1 MCH.SP.8 MCH.SP.2 MCH.SP.9 MCH.SP.3 MCH.SP.10 MCH.SP.4 MCH.SP.1

Since the case has gap
creepage and perhap
eventuality, we place s

s other ways. To protect the board from this
park gap

pect ESD to worm its way in via

Cop
Licensed under the CE
http

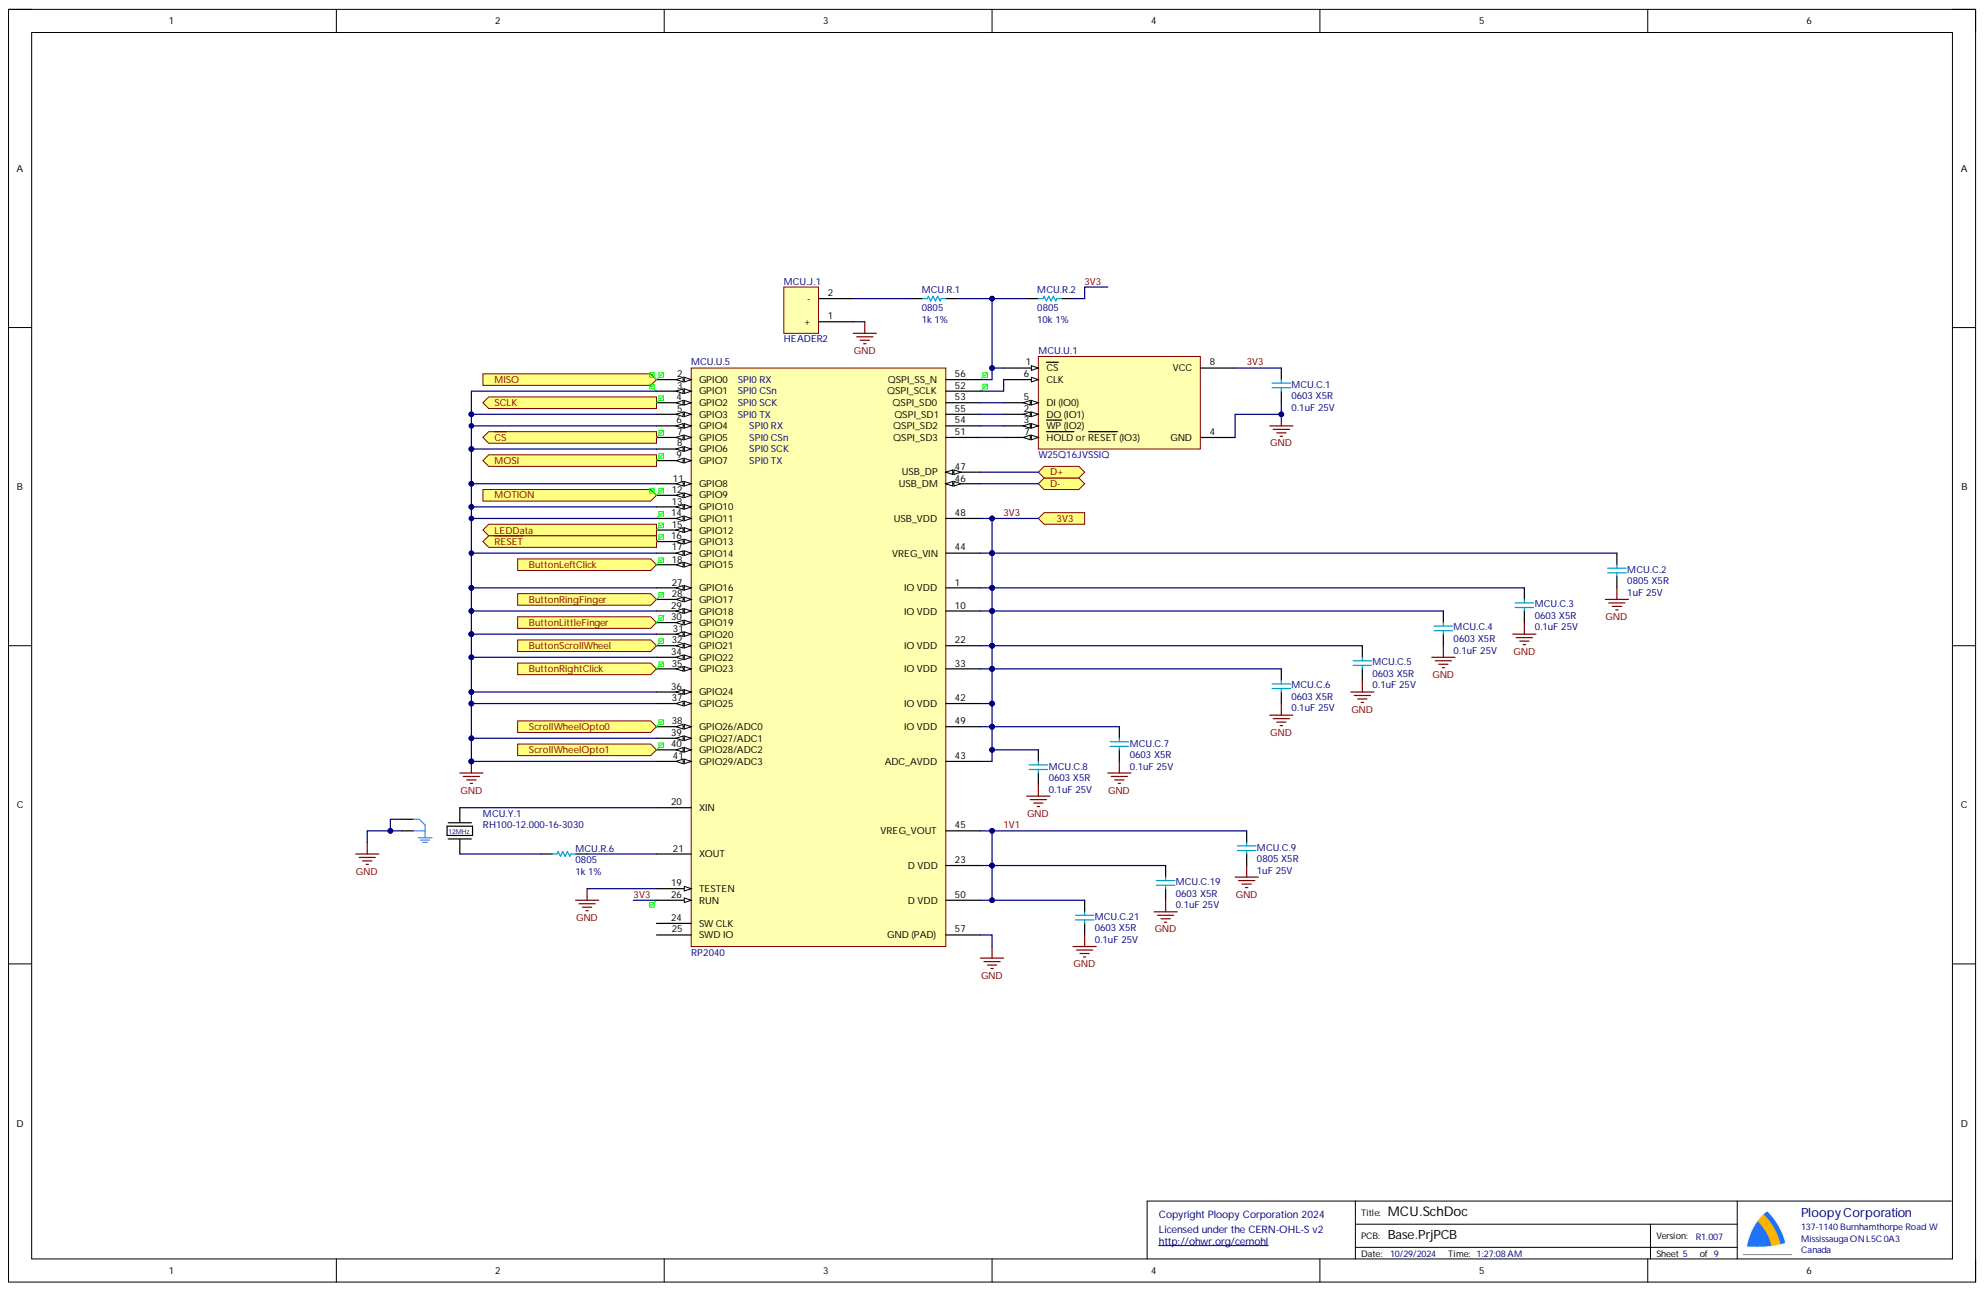
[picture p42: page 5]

SCLK MISO MOTI 6 | 3

Cop y rig h t Ploop y Cor pora tion 2 02 4 Lice n s e d u n d e r t h e CE R N -OH L -S v 2 h t t p : //ohwr .org /ce r noh l | T i t l e : MC U.S c h Doc | Plo opy C o rpo ra t i o n 1 3 7-1 1 40 B u r n h a m t hor p e Roa d W M i ssi ssa u g a O N L 5C 0A 3 C a n a d a

PC B : Base.P rjP C B | V e rsion : R 1 . 007

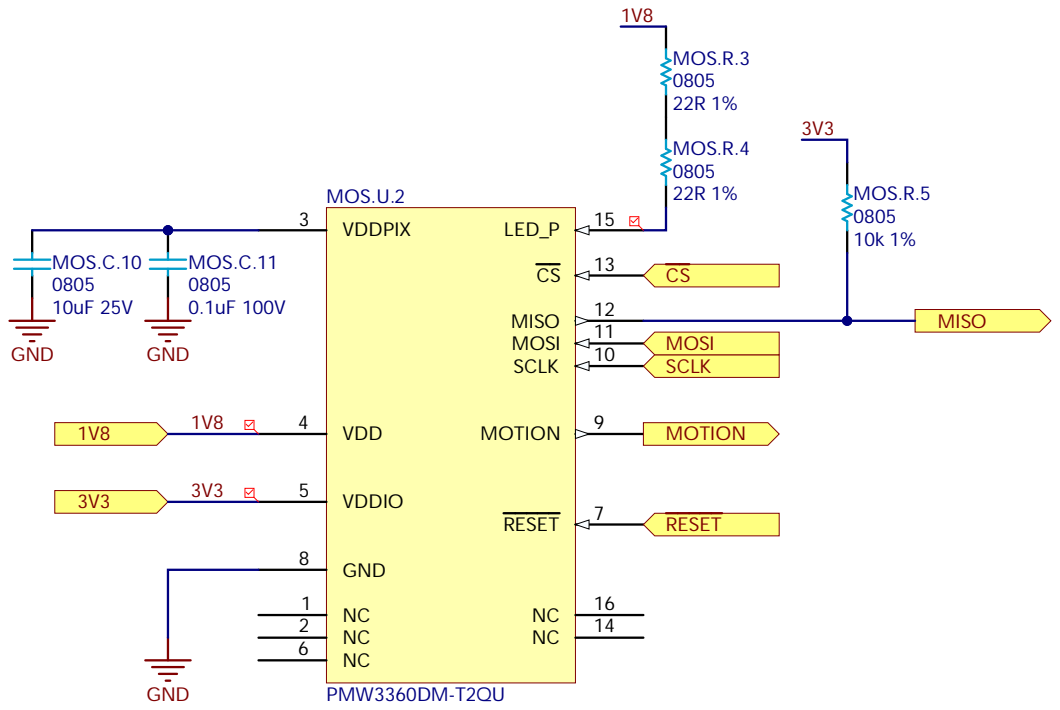
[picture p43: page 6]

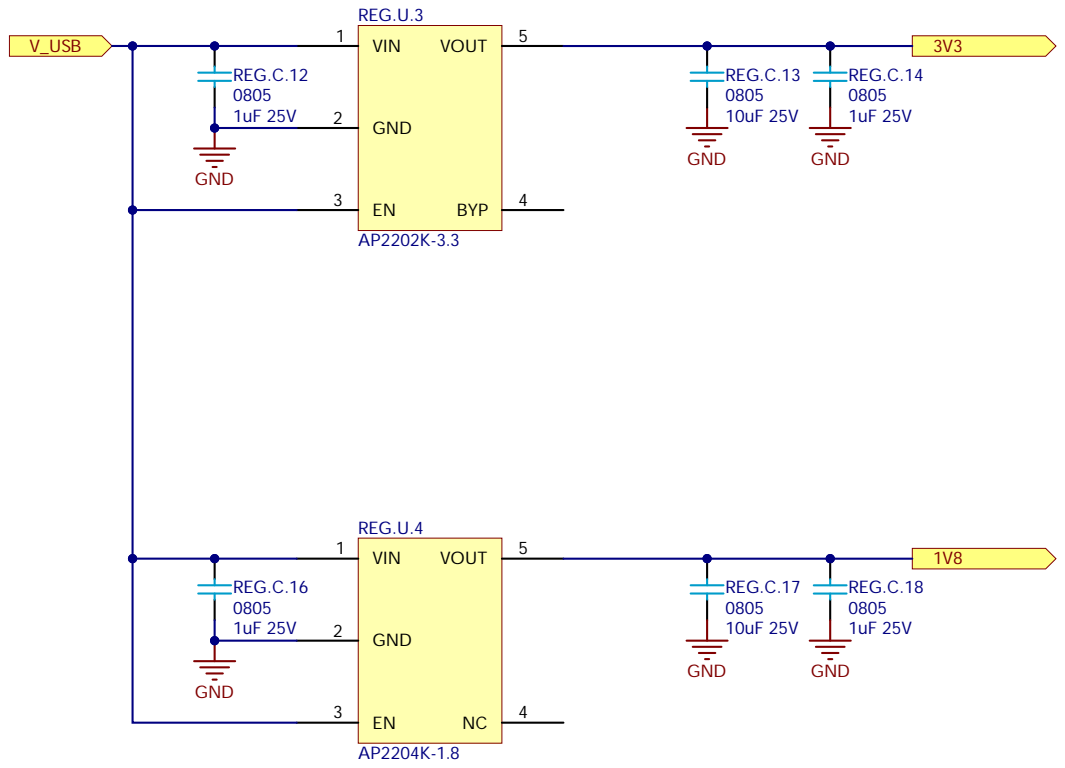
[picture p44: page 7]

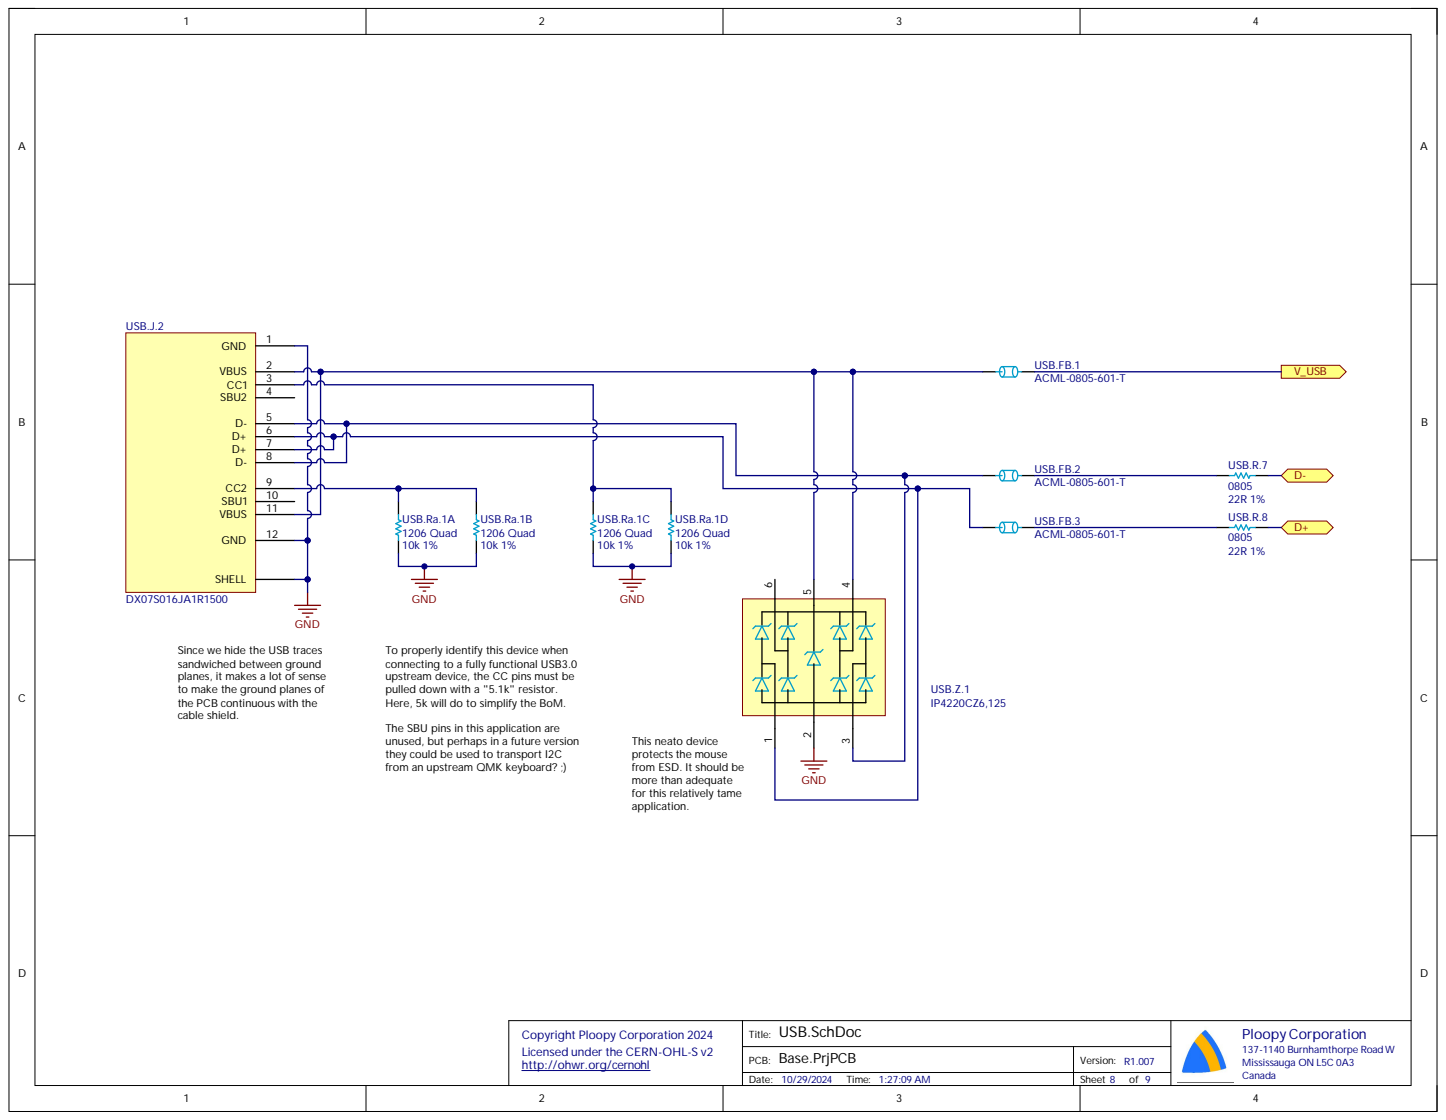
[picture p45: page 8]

Since we hide the USB traces sandwiched between ground planes, it makes a lot of sense

To properly identify this device when
connecting to a fully functional USB3.0
pulled down with a "5.1k" resistor.
Here, 5k will do to sim

to make the ground planes of
the PC
cable shield

The SB
unused, but perhap
they could be used to trans
from an up

U pins in this ap

This neato device protects the mouse

from ESD. It should be more than adequate

for this relatively tame

Cop
Licensed under the CE
http

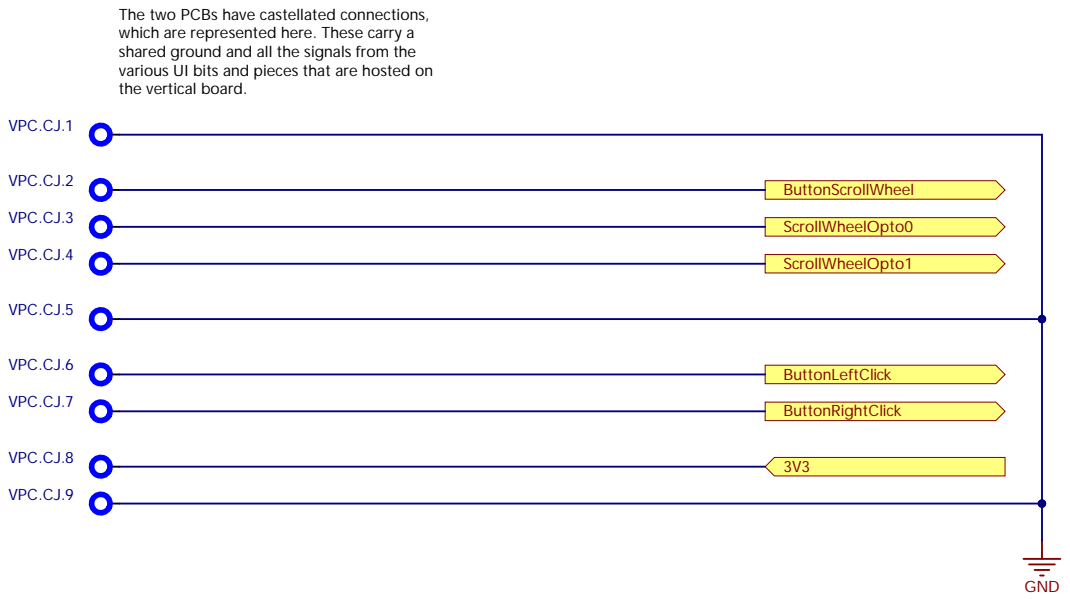
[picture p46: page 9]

The two PC
which are represented here. These carry a shared ground and all the signals from the

I bits and pieces that are hosted on

Cop
Licensed under the CE
http

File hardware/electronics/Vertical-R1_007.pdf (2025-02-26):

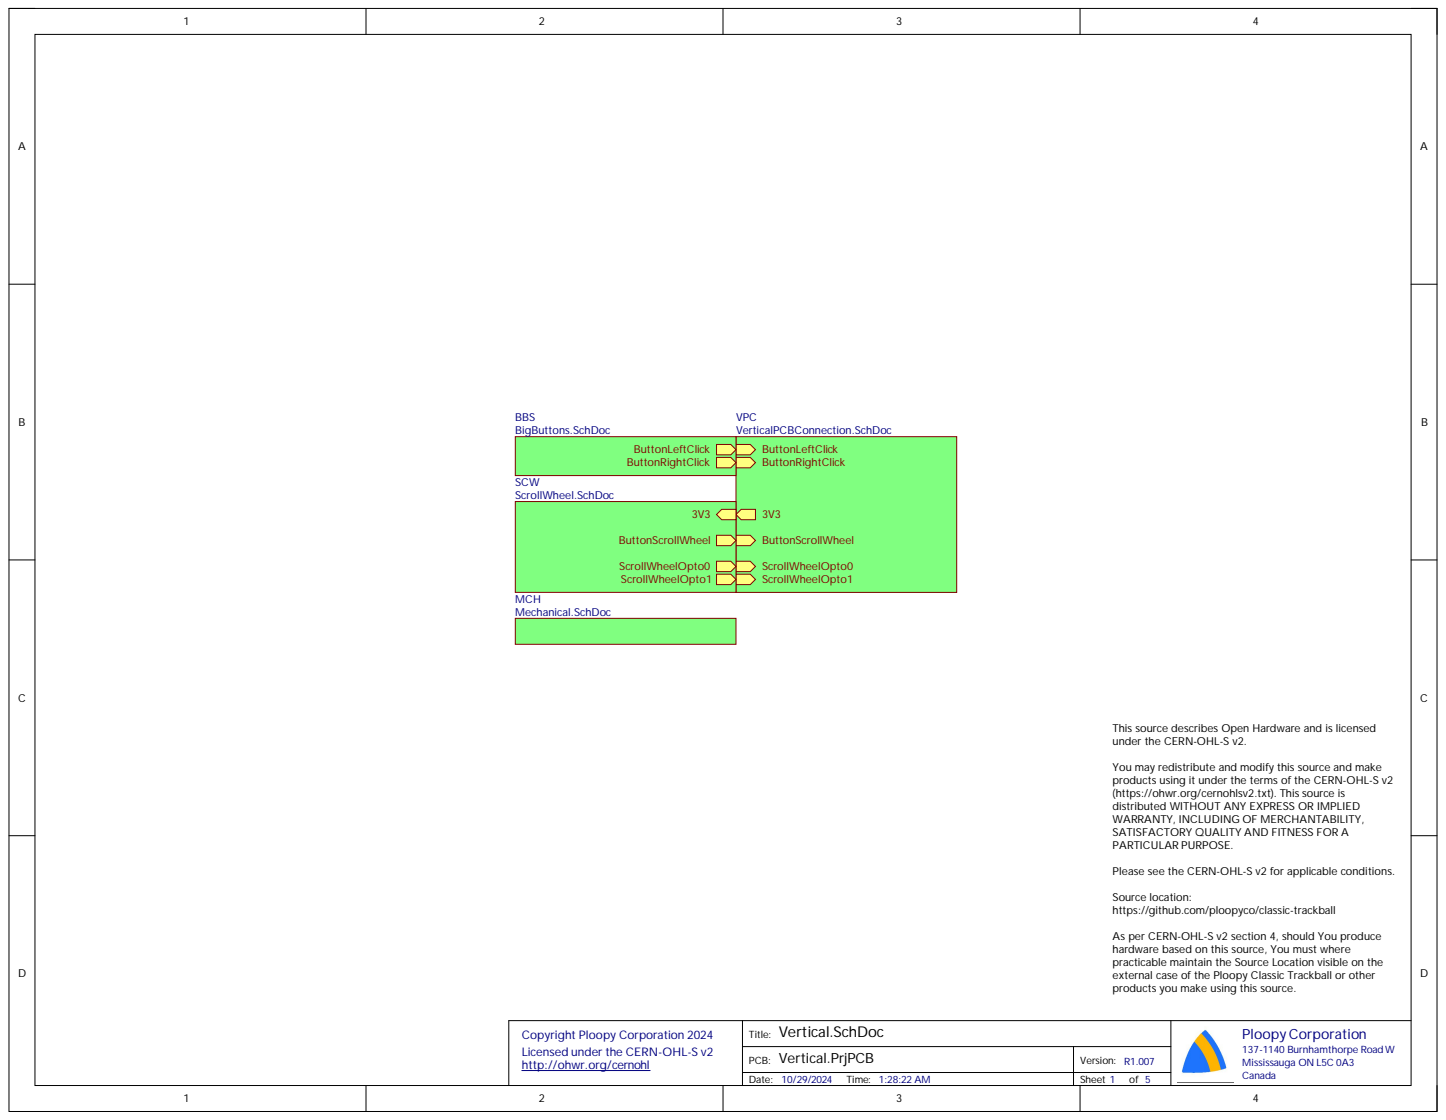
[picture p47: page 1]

This source describes Open Hardware and is licensed
under the CERN-OHL-S v2.

You may redistribute and modify this source and make
products using it under the terms of the CERN-OHL-S v2
(https://ohwr.org/cernohlsv2.txt). This source is
distributed WITHOUT ANY EXPRESS OR IMPLIED
WARRANTY, INCLUDING OF MERCHANTABILITY,
SATISFACTORY QUALITY AND FITNESS FOR A
PARTICULAR PURPOSE.

Please see the CERN-OHL-S v2 for applicable conditions.

Source location:
https://github.com/ploopyco/classic-trackball

As per CERN-OHL-S v2 section 4, should You produce
hardware based on this source, You must where
practicable maintain the Source Location visible on the
external case of the Ploopy Classic Trackball or other
products you make using this source.

Copyright Ploopy Corporation 2024
Licensed under the CERN-OHL-S v2
http://ohwr.org/cernohl

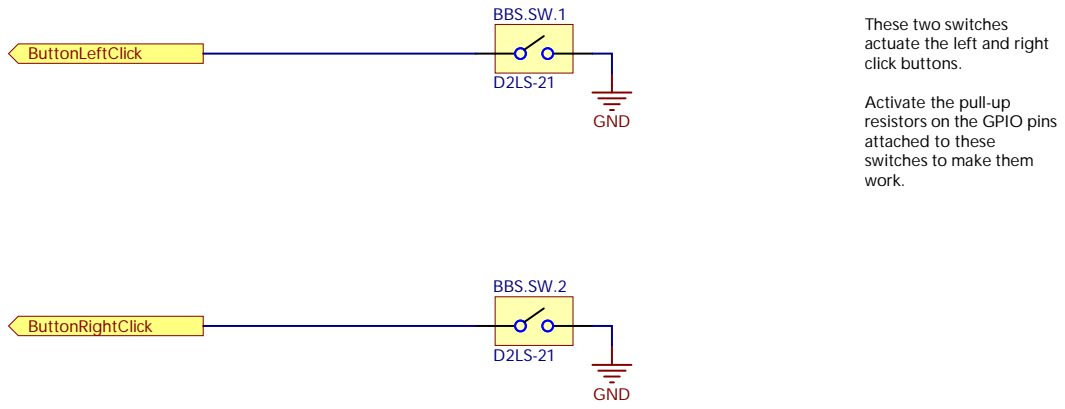
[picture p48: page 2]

These two switches
actuate the left and right
click buttons.

Activate the pull-up
resistors on the GPIO pins
attached to these
switches to make them
work.

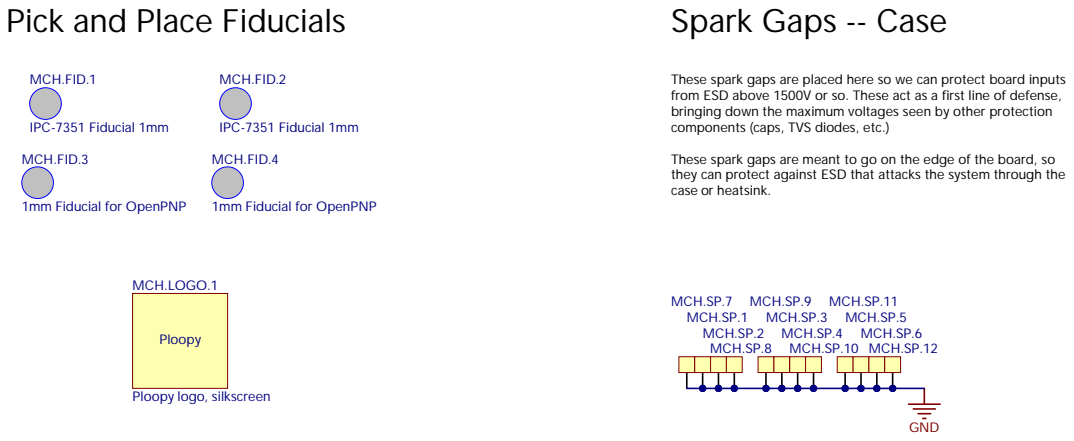
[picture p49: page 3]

Pick and Place Fiducials

These spark gaps are placed here so we can protect board inputs
from ESD above 1500V or so. These act as a first line of defense,
bringing down the maximum voltages seen by other protection
components (caps, TVS diodes, etc.)

These spark gaps are meant to go on the edge of the board, so
they can protect against ESD that attacks the system through the
case or heatsink.


The button is pretty straightforward: when the
scroll wheel gets pressed, the button is
pressed.

To make this work, the pull-up resistor on the
GPIO pin it's attached to needs to be
activated.

The scroll wheel mechanism is a 2-bit optical
encoder. The light paths are spaced 1.5
periods over the encoder wheel holes, which
should allow for the detection of the rotation
direction as well as the rotation itself.

Two IR LEDs are used as light sources; the light
from these is obstructed by the encoder wheel
built into the scroll wheel mechanism. Two
phototransistors are used to detect when the
light is blocked/not blocked by the wheel.

Typical LED forward voltage is 1.3V @20mA.
To achieve this current level with a 3.3V supply,
we'll use a 100R resistor, which is very
convenient.

At this power level, the output should be
approx 2.3mW/sr.

Since the light path distance is about 12mm,
that works out to about 2mW/cm^2, though
the actual delivered power will be lower due to
the vagaries of the obstructions in the
mechanism.

With this amount of light (and accounting for
the fact that we'll probably lose a lot of it
along the way), we are expecting 1-3mA out of
the phototransistor (see figure 6 of the
datasheet), so we size the biasing resistor
accordingly to produce a useful signal.


The two PCBs have
castellated connections,
which are represented here.
These carry a shared ground
and all the signals from the
various UI bits and pieces
that are hosted on the
vertical board.
